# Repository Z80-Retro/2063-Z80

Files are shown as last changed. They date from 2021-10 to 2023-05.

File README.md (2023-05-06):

# Retro Z80 CPU Board

This project was designed to run CP/M 2.2 from an SD card.  It should be an attainable goal for anyone that can solder through-hole parts to assemble it. Note that J10 is an optional header that allows a Sparkfun SD card breakout board [DEV-13743](https://www.digikey.com/en/products/detail/sparkfun-electronics/DEV-13743/5881845) to used instead of soldering on the surface-mount SD socket part.

Here is an easy-to-find direct link to the [PDF of the schematic](https://github.com/Z80-Retro/2063-Z80/raw/main/2063-Z80.pdf) for a quick view.

## Where to get Boards & Software

* You can order boards from any prototype PCB vendor.  For example, I show how you can order these boards from [JLCPCB](https://jlcpcb.com/) or [OSHPark](https://oshpark.com/) by uploading the gerber files found in the releases of this and the flash programmer projects as shown in this [Z80 Retro! - How To Order PC Boards](https://youtu.be/AUg_sbPnzn0) video on YouTube.
  - Gerber files for the CPU board: [2063-Z80-v3](https://github.com/johnwinans/2063-Z80/releases/download/v3/2063-Z80-gerbers.zip)
  - Gerber files for the FLASH programmer: [2065-Z80-programmer-v2](https://github.com/johnwinans/2065-Z80-programmer/releases/download/v2.0/2065-Z80-programmer-gerbers.zip) (This is used with a Raspberry PI to program the FLASH chip on the CPU board.)

* Software for this project can be found in my [2063-Z80-cpm](https://github.com/johnwinans/2063-Z80-cpm) repo.

* Note that the [FLASH programmer](https://github.com/johnwinans/2065-Z80-programmer) has been designed to work with a Raspberry PI in the event that you don't already own such programmer.  This companion programmer PCB should cost about $2 more when it is ordered at the same time as the CPU board from JLCPCB or other similar proto-board shops as shown in the [Z80 Retro! - How To Order PC Boards](https://youtu.be/AUg_sbPnzn0) video on YouTube.

## Links to Related Material

* A youtube playlist discussing this project and how to build your own can be found in [John's Basement](https://www.youtube.com/watch?v=oekucjDcNbA&list=PL3by7evD3F51Cf9QnsAEdgSQ4cz7HQZX5)
* A PDF version of the schematic can be found [here](2063-Z80.pdf).
* Here is the as-built [BOM](2063-Z80.md) with links to the datasheets for all the parts.
* Here is another [BOM](2063-Z80-sockets.md) with links to sockets for the chips.
* To configure a new PI for use with this programmer board as well as to develop Z80 code 
for the Z80 Retro board, see this [PI Setup Guide](https://github.com/johnwinans/raspberry-pi-install)
* More software for this project will be added as it evolves.

## Links to Related Datasheets Seen On YouTube

* [Z80 Datasheet PS0178](https://www.zilog.com/docs/z80/ps0178.pdf) with detailed timing diagrams.
* [Z80 User Manual UM0080](http://www.zilog.com/docs/z80/um0080.pdf) with detailed descriptions of each instruction.
* [Z80 Assembly Language Programming Manual](http://zxevo.ru/inc/Zilog_Z80_assembly_language_programming_classic.pdf) - The original version of the instructions without the OCR errors present in UM0080.
* [Z80 CPU Peripherals User Manual UM0081](http://www.zilog.com/docs/z80/um0081.pdf) discusses the CTC and SIO.
* [Z80 Family Product Specifications Handbook - 1984](http://www.bitsavers.org/components/zilog/z80/Z80_Family_Product_Specifications_Handbook_Feb84.pdf) has nicer pictures of the SIO registers.
* [Wikipedia UART Article](https://en.wikipedia.org/wiki/Universal_asynchronous_receiver-transmitter)
* [AY-3-1015D UART Datasheet](https://rocelec.widen.net/view/pdf/bvesdj0cqf/GSIIS01845-1.pdf) (Has a discussion of the 16X bit-rate clock with diagrams etc. applicable to all UARTs.)

## Serial Port Cable Parts

* [How to make IDC cables](https://youtu.be/gZ420Z-8HuU) for the serial ports.
* [IDC 2x5 connectors](https://www.amazon.com/gp/product/B07S1NFG4S)
* [IDC D-SUB 9-pin connectors (Digikey)](https://www.digikey.com/en/products/detail/assmann-wsw-components/A-DSF-09LPIII-Z/924263)
* [IDC D-SUB 9-pin connectors (Amazon)](https://www.amazon.com/Uxcell-a15030600ux0494-Female-Connector-Ribbon/dp/B00YM41NTW)

## Parallel Port Cable Parts

* [IDC 2x13 connectors](https://www.amazon.com/gp/product/B07RXK96GV)
* [IDC D-SUB 25-pin connectors (Digikey)](https://www.digikey.com/en/products/detail/amphenol-icc-commercial-products/L17DBFRA25S/1972210)
* [IDC D-SUB 25-pin connectors (Amazon)](https://www.amazon.com/Fielect-Female-Adapter-Connector-Ribbon/dp/B082GMDNTS)

## Ribbon Cable

* [40-conductor (Amazon)](https://www.amazon.com/Eowpower-40Pin-40Way-Rainbow-Ribbon/dp/B079KQ6K3Y) - peel off a
 26-pin strip and a 10-pin strip to make one parallel and one serial cable (cut the 10-pin strip in half length-wise to make two serial cables.

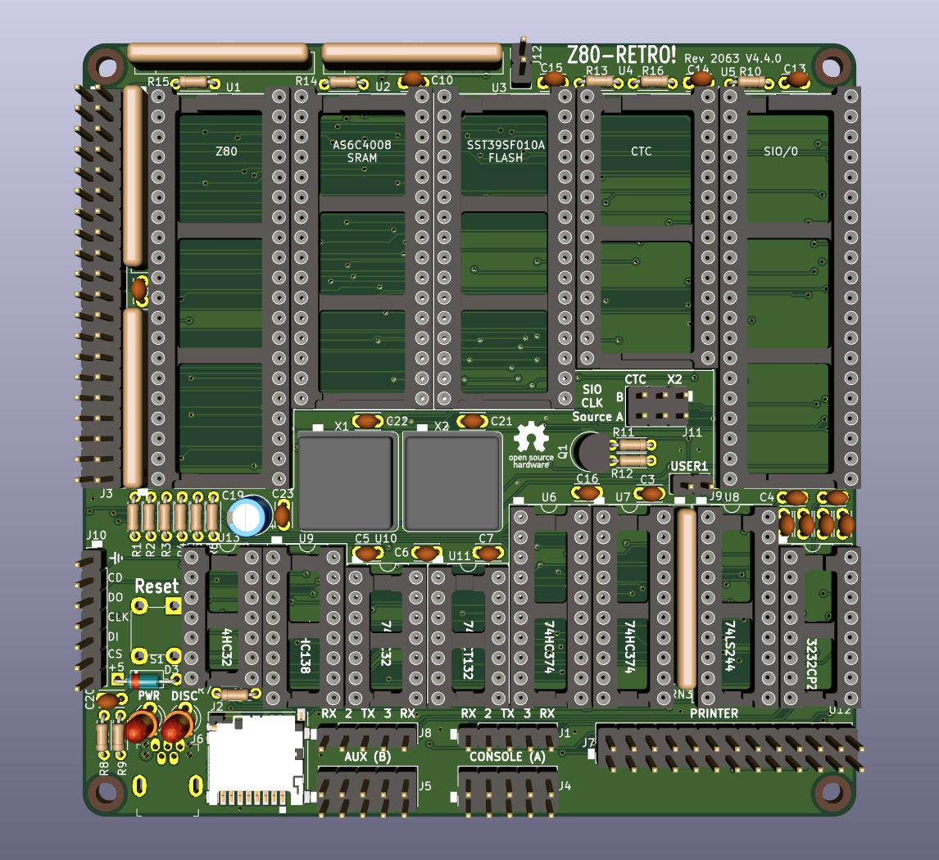
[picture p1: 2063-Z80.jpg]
PC Board Image Retro Z80 CPU Board Rev 2


# Release Notes

## V4.4.0

- Change footprint for SD socket to increase the pad size for mounting the case.
- Label R15 and R16 as DNP.
- Move the [diffs](./diffs/) into their own directory.
- V4.3.3 to V4.4.0 schematic [visual diff](https://github.com/Z80-Retro/2063-Z80/raw/main/diffs/2063-Z80-V4.3.3-V4.4.0-delta-schematic.pdf)
- V4.3.3 to V4.4.0 PCB [visual diff](https://raw.githubusercontent.com/Z80-Retro/2063-Z80/main/diffs/2063-Z80-V4.3.3-V4.4.0-delta-pcb.png)

## V4.3.3

- Increase the values of the RS232 charge pump (on U12) capacitors to improve filtering.
- V4.3.2 V4.3.3 schematic [visual diff](https://github.com/Z80-Retro/2063-Z80/raw/main/diffs/2063-Z80-V4.3.2-V4.3.3-delta-schematic.pdf)
- V4.3.2 V4.3.3 PCB [visual diff](https://github.com/Z80-Retro/2063-Z80/raw/main/diffs/2063-Z80-V4.3.2-V4.3.3-delta-pcb.png) (no changes)

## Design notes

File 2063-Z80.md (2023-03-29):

# 2063-Z80.sch

## Tue Mar 28 20:43:38 2023

## Eeschema 5.1.5+dfsg1-2build2

## Component Count:86

Ref | Qty | Value | Digikey | Datasheet | Description
----|-----|-------|---------|-----------|------------
C1, C11, C12, C20 | 4 | .47 | 399-14039-1-ND | https://api.kemet.com/component-edge/download/datasheet/C315C474K5R5TA7303.pdf | Unpolarized capacitor, small symbol
C2, C3, C4, C5, C6, C7, C8, C9, C10, C13, C14, C15, C16, C21, C22, C23 | 16 | .1 | 399-9859-1-ND | https://api.kemet.com/component-edge/download/specsheet/C315C104M5U5TA7303.pdf | Unpolarized capacitor, small symbol
C17 | 1 | .1 | 1276-1935-1-ND | https://www.mouser.com/datasheet/2/585/MLCC-1837944.pdf | Unpolarized capacitor, small symbol
C18 | 1 | 10uF | 1276-1298-1-ND | https://media.digikey.com/pdf/Data%20Sheets/Samsung%20PDFs/CL21A106MQFNNNE_Spec.pdf | Polarized capacitor, small US symbol
C19 | 1 | 10uF | P975-ND | https://industrial.panasonic.com/cdbs/www-data/pdf/RDF0000/ABA0000C1059.pdf | Polarized capacitor, small US symbol
C24 | 1 | .1 | 1276-1935-1-ND | https://www.mouser.com/datasheet/2/585/MLCC-1837944.pdf | Unpolarized capacitor, small symbol
D1, D2 | 2 | LED_ALT | 1080-1122-ND | https://media.digikey.com/PDF/Data%20Sheets/Everlight%20PDFs/ds300034.pdf | Light emitting diode, filled shape
D3 | 1 | 1N914 | 1N4148FSCT-ND | http://www.vishay.com/docs/85622/1n914.pdf | 100V 0.3A Small Signal Fast Switching Diode, DO-35
H1, H2, H3, H4 | 4 | MountingHole |  |  | Mounting Hole without connection
J1, J8 | 2 | Conn_01x05 | S1011EC-05-ND | https://media.digikey.com/PDF/Data%20Sheets/Sullins%20PDFs/xRxCzzzSxxN-RC_ST_11635-B.pdf | Generic connector, single row, 01x05, script generated (kicad-library-utils/schlib/autogen/connector/)
J2 | 1 | DM3D-SF(41) | H126097CT-ND (alternate: 114-00841-68-1-ND) | https://www.hirose.com/product/document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 | Micro SD Card Socket with card detection pins
J3 | 1 | Conn_02x20 | S2011EC-20-ND | https://drawings-pdf.s3.amazonaws.com/11636.pdf | Generic connector, double row, 02x20, counter clockwise pin numbering scheme (similar to DIP packge numbering), script generated (kicad-library-utils/schlib/autogen/connector/)
J4, J5 | 2 | Conn_02x05 | 1849-1002-ND |  | Generic connector, double row, 02x05, odd/even pin numbering scheme (row 1 odd numbers, row 2 even numbers), script generated (kicad-library-utils/schlib/autogen/connector/)
J6 | 1 | 0548190519 | A135698-ND | https://www.molex.com/pdm_docs/sd/548190519_sd.pdf | CONN RCPT USB2.0 MINI B 5P R/A
J7 | 1 | Conn_02x13 | S2011EC-13-ND | https://drawings-pdf.s3.amazonaws.com/11636.pdf | Generic connector, double row, 02x13, top/bottom pin numbering scheme (row 1: 1...pins_per_row, row2: pins_per_row+1 ... num_pins), script generated (kicad-library-utils/schlib/autogen/connector/)
J9, J12 | 2 | Conn_01x02 | S1011EC-02-ND | https://media.digikey.com/PDF/Data%20Sheets/Sullins%20PDFs/xRxCzzzSxxN-RC_ST_11635-B.pdf | Generic connector, single row, 01x02, script generated (kicad-library-utils/schlib/autogen/connector/)
J10 | 1 | Conn_01x07 | S1011EC-07-ND | https://media.digikey.com/PDF/Data%20Sheets/Sullins%20PDFs/xRxCzzzSxxN-RC_ST_11635-B.pdf | Generic connector, single row, 01x07, script generated (kicad-library-utils/schlib/autogen/connector/)
J11 | 1 | Conn_02x03 | 2057-PH2-06-UA-ND | https://app.adam-tech.com/products/download/data_sheet/202065/ph2-xx-ua-data-sheet.pdf | Generic connector, double row, 02x03, odd/even pin numbering scheme (row 1 odd numbers, row 2 even numbers), script generated (kicad-library-utils/schlib/autogen/connector/)
LOGO1 | 1 | OSHW_Logo |  |  | Open Hardware logo, small
LOGO2 | 1 | OSHW_Logo |  |  | Open Hardware logo, small
NT1, NT2 | 2 | Net-Tie_2 |  | ~ | Net tie, 2 pins
Q1 | 1 | PN2222 | 1514-PN2222APBFREE-ND | https://my.centralsemi.com/datasheets/PN2221-2222A.PDF | NPN transistor, emitter/base/collector
R1, R3, R5 | 3 | 2K7 | CF18JT2K70CT-ND | https://www.seielect.com/catalog/sei-cf_cfm.pdf | Resistor
R2, R4, R6 | 3 | 4K7 | CF18JT4K70CT-ND | https://www.seielect.com/catalog/sei-cf_cfm.pdf | Resistor
R7, R10, R13, R14 | 4 | 10K | CF18JT10K0CT-ND | https://www.seielect.com/catalog/sei-cf_cfm.pdf | Resistor
R8, R9 | 2 | 680 | CF18JT680RCT-ND‎ | https://www.seielect.com/catalog/sei-cf_cfm.pdf | Resistor
R11, R12 | 2 | 1K | CF18JT1K00CT-ND‎ | https://www.seielect.com/catalog/sei-cf_cfm.pdf | Resistor
R15, R16 | 2 | 120 | CF18JT120RCT-ND | https://www.seielect.com/catalog/sei-cf_cfm.pdf | Resistor
RN1, RN2, RN3, RN4, RN5 | 5 | 10K | 4609X-101-103LF-ND‎ | https://www.bourns.com/docs/Product-Datasheets/4600x.pdf | 8 resistor network, star topology, bussed resistors, small symbol
S1 | 1 | 1825910-6 | 450-1650-ND | https://www.te.com/commerce/DocumentDelivery/DDEController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 | SWITCH TACTILE SPST-NO 0.05A 24V
U1 | 1 | Z80-CPU | 269-3898-ND | https://www.zilog.com/manage_directlink.php?filepath=docs/z80/um0080 | 8-bit General Purpose Microprocessor, DIP-40
U2 | 1 | AS6C4008-55PCN | 1450-1178-5-ND‎ | https://www.alliancememory.com/wp-content/uploads/pdf/AS6C4008.pdf | 512K x 8 Low Power CMOS RAM, DIP-32
U3 | 1 | SST39SF010 | SST39SF010A-70-4C-PHE-ND‎ | https://ww1.microchip.com/downloads/en/DeviceDoc/20005022C.pdf | Silicon Storage Technology (SSF) 128k x 8 Flash ROM
U4 | 1 | Z80-CTC | 269-3914-ND | http://www.zilog.com/docs/z80/ps0181.pdf | Z80 CTC DIP-28
U5 | 1 | Z80-SIO-0 | 269-5062-ND‎ | http://www.zilog.com/docs/z80/ps0183.pdf | SCC Serial Communication Controller, DIP-40
U6, U7 | 2 | 74HC374 | 296-12806-5-ND | https://www.ti.com/lit/ds/symlink/cd74hct374.pdf | 8-bit Register, 3-state outputs
U8 | 1 | 74LS244 | 296-36148-5-ND | https://www.ti.com/lit/ds/symlink/sn74ls241.pdf | 8-bit Bus Buffer 3-State outputs
U9 | 1 | 74HC138 | 296-SN74HC138AN-ND | https://www.ti.com/lit/ds/symlink/sn54hc138.pdf | Decoder 3 to 8 active low outputs
U10, U13 | 2 | 74HC32 | 296-12803-5-ND | https://www.ti.com/lit/ds/symlink/cd74hc32.pdf | Quad 2-input OR
U11 | 1 | 74HCT132 | 296-2090-5-ND | https://www.ti.com/lit/ds/symlink/cd74hc132.pdf | Quad 2-input NAND Schmitt trigger
U12 | 1 | ICL3232CPZ | ICL3232CPZ-ND‎ | https://www.renesas.com/us/en/document/dst/icl3221-icl3222-icl3223-icl3232-icl3241-icl3243-datasheet | 3.0V to 5.5V, Low-Power, up to 1Mbps, True RS-232 Transceivers Using Four 0.1μF External Capacitors
U20 | 1 | LM1117-3.3 | NCP1117ST33T3GOSCT-ND | https://www.onsemi.com/pdf/datasheet/ncp1117-d.pdf | 800mA Low-Dropout Linear Regulator, 1.8V fixed output, TO-220/TO-252/TO-263/SOT-223
X1 | 1 | ACH-10.000MHZ-EK | 535-9167-5-ND | https://abracon.com/Oscillators/ACH.pdf | Crystal Clock Oscillator, DIP8-style metal package
X2 | 1 | ECS-2100A-018 | XC231-ND‎ | https://ecsxtal.com/store/pdf/ecs_2100.pdf | Crystal Clock Oscillator, DIP8-style metal package

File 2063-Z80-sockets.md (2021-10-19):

## IC Sockets

You can buy fancy expensive ones, or you can buy cheap ones.
I used the cheap ones.  

Alternately, you can just solder the chips into the PCB.

As a tinkerer, the thing that is wrong with that is that it makes it very hard to 
recycle/repurpose the chips for something else in the future.  And with the 2021
chip-shortage in full-force on as I type this, being able to recycle chips is 
VERY appealing!

Be honest with yourself before sinking more money into sockets than the cost of the chips 
that go into them.  I expect the cheap ones to last for at least a decade or two.  Cheap
sockets in my hobby projects from 30 years ago are still doing fine.

Gold plating is better than tin.  Machined pins (see the oscillator sockets) are better than
stamped spring-metal pins. 

Ref | Qty | Value | Digikey | Datasheet | Description
----|-----|-------|---------|-----------|------------
U1,U5 | 2 | Socket | AE10008-ND | http://www.assmann-wsw.com/uploads/datasheets/ASS_0810_CO.pdf | DIP-40
U2,U3 | 2 | Socket | 2057-ICS-632-T-ND | https://app.adam-tech.com/products/download/data_sheet/199581/ics-6xx-t-data-sheet.pdf | DIP-32
U4 | 1 | Socket | 2057-ICS-628-T-ND | https://app.adam-tech.com/products/download/data_sheet/199581/ics-6xx-t-data-sheet.pdf | DIP-28
U10,U13,U11 | 3 | Socket | 2057-ICS-314-T-ND | https://app.adam-tech.com/products/download/data_sheet/199582/ics-3xx-t-data-sheet.pdf | DIP-14
U9,U12 | 2 | Socket | 2057-ICS-316-T-ND | https://app.adam-tech.com/products/download/data_sheet/199582/ics-3xx-t-data-sheet.pdf | DIP-16
U6,U7,U8 | 3 | Socket | 2057-ICS-320-T-ND | https://app.adam-tech.com/products/download/data_sheet/199582/ics-3xx-t-data-sheet.pdf | DIP-20

# Sockets for the Oscillators

Metal can oscillators have wires for pins.  In my experience they tend to sit loosely in 
regular sockets and do better in machined-pin sockets.

For these 4-pin parts you have two options.  Either order a relatively expensive pair of 
sockets ready to solder in as-is or order a pair with extra pins and remove the ones you don't
want and then solder in. 

I went the latter route because I already had several 8-pin sockets on hand.

To remove the extra pins from the fully loaded sockets, use a small pliers to grab the pins 
to be removed from the bottom of the socket and push them out the top.

Look at the photos of each type and you'll see what I mean.

Ref | Qty | Value | Digikey | Datasheet | Description
----|-----|-------|---------|-----------|------------
X1,X2 | 2 | Socket | ED90427-ND | https://www.mill-max.com/catalog/download/2017-11:134.pdf | OSC-4 (a whopping $1.50 each!)
X1,X2 | 2 | Socket | AE10011-ND | http://www.assmann-wsw.com/uploads/datasheets/ASS_4852_CO.pdf | DIP-8 ($.50 each)

## Shorting Blocks

These are for selecting the clock sources for the SIO, user jumper, and 
RS-232 TX/RX pin number selection.

Ref | Qty | Value | Digikey | Datasheet | Description
----|-----|-------|---------|-----------|------------
J11,J9,J1,J8 | 7 | S9337-ND | https://s3.amazonaws.com/catalogspreads-pdf/PAGE128-129%20.100%20JUMPER.pdf | Shorting Block | Shorting Jumper

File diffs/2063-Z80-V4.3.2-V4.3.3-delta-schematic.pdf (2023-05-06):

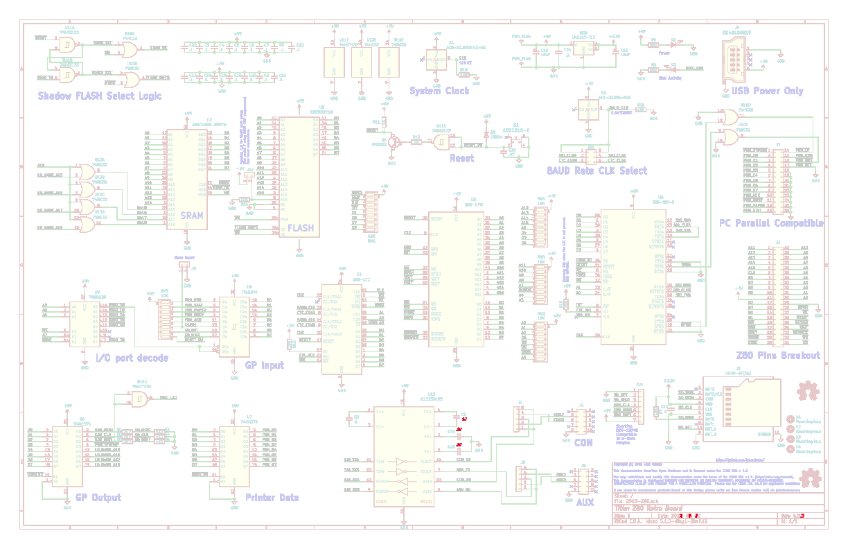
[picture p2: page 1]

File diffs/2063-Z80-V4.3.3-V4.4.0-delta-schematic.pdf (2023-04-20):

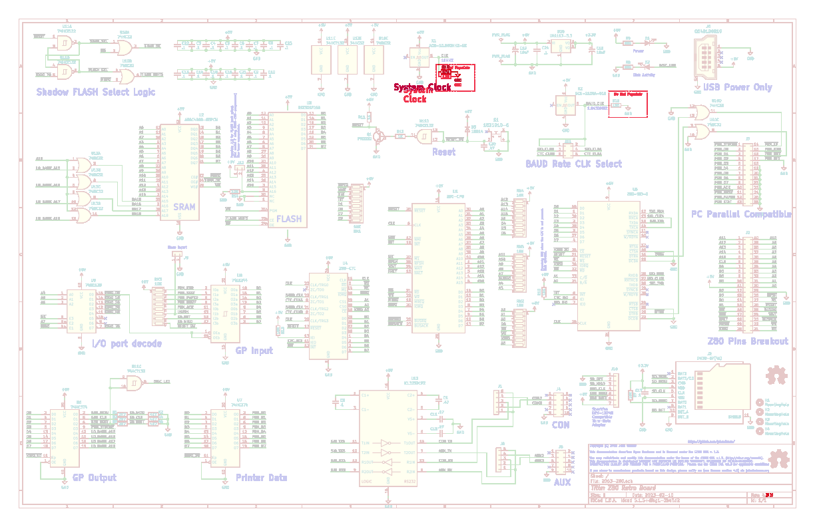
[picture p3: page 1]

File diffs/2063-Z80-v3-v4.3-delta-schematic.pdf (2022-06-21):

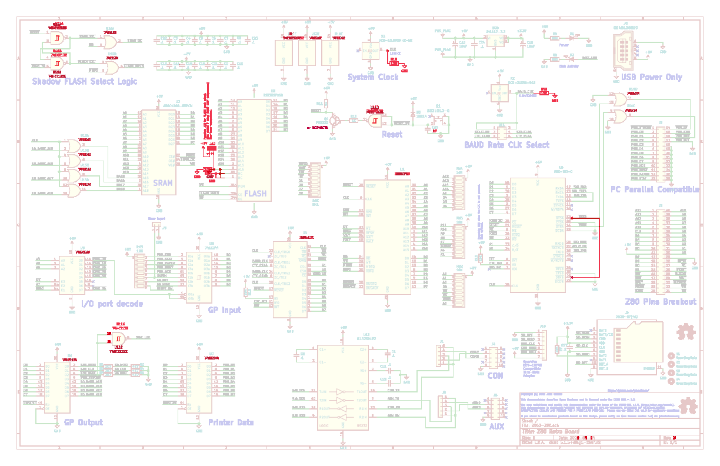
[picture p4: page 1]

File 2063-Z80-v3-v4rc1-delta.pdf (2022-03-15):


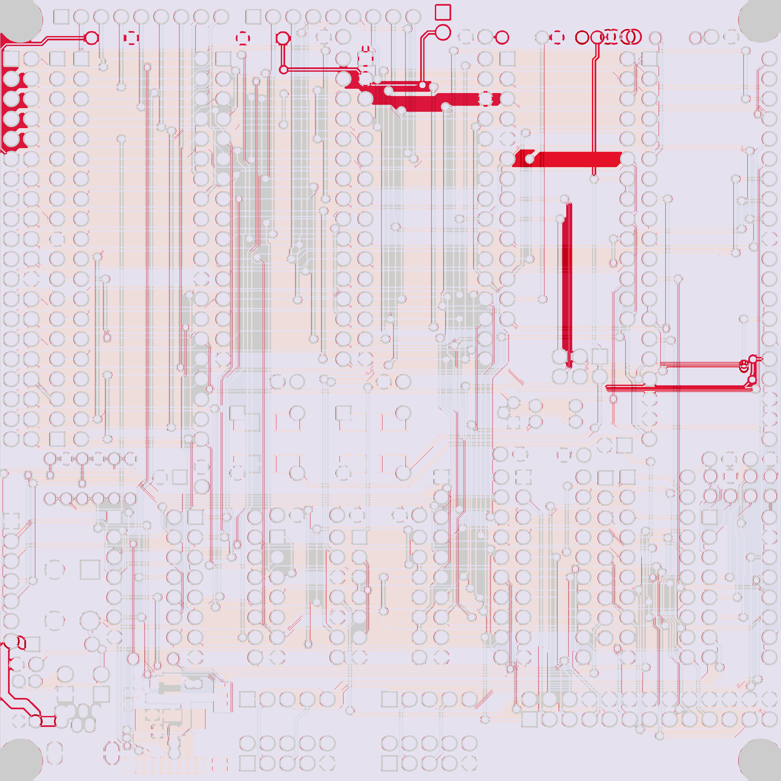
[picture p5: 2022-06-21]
diffs/2063-Z80-v3-v4.3-delta-pcb.png

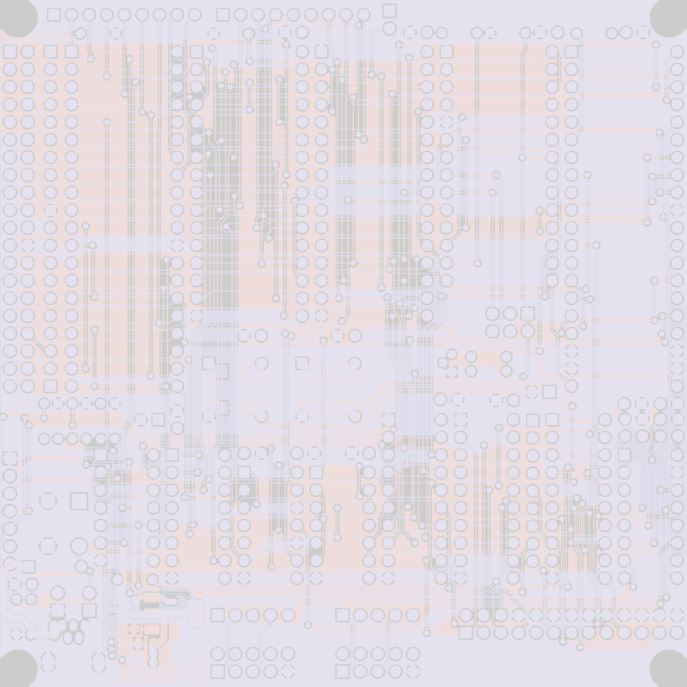
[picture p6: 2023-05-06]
diffs/2063-Z80-V4.3.2-V4.3.3-delta-pcb.png

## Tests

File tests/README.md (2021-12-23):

# Basic test applications for the Z80 Retro board.

These applications require the use of `z80asm`.  You can install it like this:

	sudo apt install z80asm

Assemble these test applications like this:

	make world

Download them into the FLASH by using the `flash` programming application in the 
[2065-Z80-programmer](https://github.com/johnwinans/2065-Z80-programmer/tree/master/pi) 
project in github.  If you cloned the 2065-Z80-programmer project into your
home directory and built it on your PI then you can program these files like this:

	~/2065-Z80-programmer/pi/flash < blinky1.bin

## Test Programs

### blinky1.asm
Flash the SD card select LED.  This runs entirely from the FLASH (does not use SRAM).

### blinky2.asm
Flash the SD card select LED.  This copies itself from the FLASH into the SRAM and then runs from there.

### blinky3.asm
Flash the SD card select LED and at the same time, count on the printer port data lines.

### hello_sio1.asm
Test the SIO ports in polled mode.

### hello_sio2.asm
Test the SIO ports in IRQ mode.

### hello_ctc2.asm
Test the CTC with IRQs and print an 'uptime' counter using the SIO.

## bank_select.asm
Test the SRAM blank select logic by padding and dumping regions of memory in different banks.

## hello_lpt.asm
Test the printer port by priting a 'hello world' type message.

## hello_lpt2.asm
Test the printer port by priting gaudy banners.

## io.asm
Equates for the IO ports on the Z80 Retro! board.

## sio.asm
Simple driver for the SIO.

## hexdump.asm
A library to print a memory hex dump.

## ctc.asm
Simple driver for the CTC.

## lpt.asm
Simple driver for the printer.

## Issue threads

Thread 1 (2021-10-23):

Rev 3: /PRN_LF should not be originated from /RTSA

johnwinans, 2021-10-23:
The /PRN_LF signal is intended to be manually changed under software control only.
I ran out of space on the PCB and decided to use an output pin on the SIO as a general-purpose port.  It will work if the intent is to drive the pin low.  But it will not work as expected when driving it high.

Z80 Family CPU Peripherals User Manual UM008101-0601 says this on page 212:

> RTSA, RTSB Request To Send (outputs, active Low). When the /RTS bit is set, the RTS output goes Low. When the RTS bit is reset in the Asynchronous mode, the output goes High after the transmitter is empty.

Therefore, driving the pin low will work as expected.

To drive it high an a Rev 3 board, there are two options:

1. Cut the track on J7 pin 14 and wire it to +5v (which is a better hard-wired default than low)
2. Cut the track on U10 pin 13 and add a wire to connect it to U5, pin 25 /DTRB (which is a GP output pin)

In Rev 4, I will re-route this pin to U5, pin 25 (option 2 above)

johnwinans, 2021-12-01:
Done in Rev 4

Closed 2021-12-01.

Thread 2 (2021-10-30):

Low slew-rate power might not assert /RESET long enough

johnwinans, 2021-10-30:
After doing some testing with a range of USB power supplies/chargers I have noticed that one of mine will ramp up the voltage slow enough to prevent the /RESET signal from remaining asserted long enough to properly start the Z80.

This has no impact on the ability to use the reset button.

To 'fix' this, I changed C20 to .47uF.  This will keep the /RESET signal asserted five times longer after initial power-up and "works for me" on all the USB power supplies that I have around to test with.

Increasing the size of C20 is OK within reason.  Keep in mind that the reset-button (S1) shorts out C20 to reset the system.  The switch will not last very long if C20 is large!  I'd advise not using anything more than 1uF for C20.

johnwinans, 2021-12-01:
I changed C20 to .47uF in the Rev4 version of the schematic.

Closed 2021-12-01.

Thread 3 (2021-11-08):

Allow alternate SD card sockets

johnwinans, 2021-11-08:
Due to the galactic parts-shortage, Digikey, Mouser, and Newark are all on backorder for the Hirose DM3D-SF SD card socket in the Rev 3 design.

If a Rev4 board is produced, adjust the footprint to allow for an alternate socket (such as the Molex 1051620001) to be used.
[It looks like the Molex could be made to fit on the same pads IFF the keep-out areas are increased and a second card-det landing is added.]

sebsch2000, 2021-11-17:
Amphenol 114-00841-68 has the same footprint as the Hirose part. Right now Mouser has 4.813 of them in stock (Mouser part no. 523-114-00841-68).

jackrubin, 2021-11-18:
Who’s on first? Does this mean that there is no need for a Rev 4 board spin and I can build out one of your Rev 3 sets?

Thanks,
Jack

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

sebsch2000, 2021-11-18:
Well, I built a rev 3 board this week. I ordered the parts from Mouser and Digikey. Had to replace the Hirose connector with the Amphenol one and the ICL3232CPZ (U12) with the MAX232N which is basically the same. The test programs worked as they should.

jackrubin, 2021-11-18:
That’s good – if you still have a spare, I’d like to buy one board + programmer set from you. Please let me know the cost and PayPal info.

Thanks,
Jack

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

johnwinans, 2021-11-18:
How did I not find the Amphenol 114-00841-68 part????  That is fantastic!
I'll add a note marking that as an alternate and take a pass on the footprint hacking.

jackrubin, 2021-11-26:
Please push the rev/bom changes up to the github repository when you get a chance.
Thanks!

johnwinans, 2021-12-01:
There is at least one alternate that does not require a footprint modification.  I am not going to leave well enough alone.

Closed 2021-12-01.

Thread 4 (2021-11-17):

Add A16 jumper to FLASH

johnwinans, 2021-11-17:
Add a jumper & pullup on the FLASH A16 pin to allow alternate BOOT images.
Note that this is only useful when using a stand-alone FLASH programmer as the in-circuit programmer design will not work when A16(, A17 or A18) is high.

johnwinans, 2021-12-01:
So done in Rev4

Closed 2021-12-01.

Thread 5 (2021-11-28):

Clock overshoot

johnwinans, 2021-11-28:
Add terminating resistors to the clock signal traces to reduce overshoot & ringing.

johnwinans, 2021-12-01:
I added end-terminating resistors to Rev4.  It looks like 120 will reduce the concern a bit.
Source-termination might help too but I am out of space on the board.

Closed 2021-12-01.

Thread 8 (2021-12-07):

10MHZ clock might be too fast for the FLASH chip I specified.

johnwinans, 2021-12-07:
While my board has been running fine at 10MHZ, the timing on FLASH_MREQ is too tight to meet the official worst-case specification... even with the 55ns version of the FLASH.

The solution if you run into trouble is to run the main clock at 8MHZ.  I will change the design to officially run at 8.

On the YouTube comments: https://www.youtube.com/watch?v=w5LYCHml4A8

Torshak observed:
As always, great and very helpfull video.
I have a observation regarding memory access time though. I am trying to read Z80 opcode fetch timings, and I don't think you have entire 150ns. Yes, you have 1.5 periods, but... MREQ signal does not fall together with clock falling egde but it takes it up to 55 ns. Then Z80 expects data to be stable 25 ns before rising edge of the clock. (all timings for 10Mhz version) so you are left with 70ns, and that's wihtout glue logic. Of course this is almost the absolute worst scenario. Unless I am reading it wrong... which would not be the first time ;)

Then I replied with this:
BLAST IT ALL!!!!  I was looking at a page of the datasheet that included a wait-state in the diagram!   It looks like the 55 and 25 numbers are right for the 10MHZ Z80.. The FLASH that I used has a 70ns access time (and the RAM is 55).  Revising my understanding and NOT including a stinking wait-state the tightest memory cycle duration is 150ns - 55ns - 25ns = 70ns.
Fortunately, the SRAM has no decoding per-se  and the OE to DATA time is 30ns (which is fine with the extra U10 27ns delay.)
The FLASH is a bit more of a problem.  FLASH_MREQ can be delayed by U10 by up to 27ns.
I hang my head in shame!
Luckily, at 8MHZ, we see 125*1.5 - 60 - 30 = 97.5nsec
The worst-case FLASH_MREQ time (delayed by 27ns) is then 70.5nsec  :-D
I think I will /officially/ slow the main clk to 8MHZ and observe that I have been living on the edge by overclocking mine at 10!

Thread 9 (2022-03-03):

Is board silkscreen for U11 incorrect on 2063.4?

joelburton, 2022-03-03:
The board silkscreen on U11 is `'00` (suggesting a 74HCT00) --- however, the schematic/values/BOM suggests that is a 74HCT132.

Is this just a mislabel on the board? Or am I misunderstanding something significant?

johnwinans, 2022-03-03:
The 132 is the correct part!  The reason is that U11D must have a
Schmitt trigger.

Thanks for mentioning it. I will update the silkscreen.

I recorded a video explaining the need for the Schmitt here:

https://youtu.be/LDce9foQ2Ag

I have been working on a playlist discussing every detail of this
project here:

https://www.youtube.com/playlist?list=PL3by7evD3F51Cf9QnsAEdgSQ4cz7HQZX5

This month I will be adding details on how to port CP/M onto it.

-John

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

johnwinans, 2022-03-22:
I updated the silkscreen.  It will appear in v4rc2

Closed 2022-03-22.

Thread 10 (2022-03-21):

Possibly useful advice: connecting console to computer w/o RS232 serial

joelburton, 2022-03-21:
I have a RS232 terminal, but a friend building the board does not and doesn't even have a serial port on her computer. The design doesn't expose an easy way to connect a 5v Tx/Rx for a FTDI->USB connection.

I doubt there's space to add that to the board (maybe above the printer connection?), but something that is working for us is a RS232 voltage -> 5v converter (we're using https://www.amazon.com/gp/product/B07LBDZ9WG/). This can be connected to a standard FTDI USB cable.

johnwinans, 2022-03-21:
This is a good idea... and it figures... I *just* ordered some v4 boards last week to verify that design. :-D

I don't have a serial port on mine either.  I use a USB/RS232 adapter like one of these:
https://www.amazon.com/Sabrent-RS-232-Adapter-Prolific-SBT-USC6K/dp/B000A1KD1K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

But this makes me think.  There are likely a number of potential users the might want to go USB-direct.

With the product you mention, you could solder in wires to the U12 pin holes and run them to the adapter board. With the header on the side next to the DB25 seems awkward to try to directly mate.  (That is actually how I did the first version of this board as I messed up U12 completely.)

If you leave U12 unpopulated, we could add a 1-row header that could match an available 3rd party USB TTL adapter.  These appear to be pinned the same way.
https://www.sparkfun.com/products/14050
https://www.sparkfun.com/products/9716

I'm not sure that I'd want to power the Retro board from a PC USB port... and would definitely not think of powering a PI (FLASH programmer) from it.  (I *always* Power my retro FROM the PI when I have the FLASH programmer installed.)  But it might be worth providing a way to add a jumper or something to allow it.

It should be easy to put a header just south of the printer port or even under U12 (so you could either install a header OR the U12 socket.)
If you install a right-angle header then the adapter would lay flat (which would be my preference.)

What do you think?

joelburton, 2022-03-21:
Putting the headers in the center of U12 is an interesting idea an could help those that don't populate it; that wouldn't use up any of the precious board space :)

joelburton, 2022-03-21:
Those Sparkfun boards are what a lot of other projects (like the rc2014s) make their pins compatible for, so a lot of people have them lying about.

johnwinans, 2022-03-22:
I was torn between the header at the bottom under the printer port and overlaying U12.
I like the idea of building the board with both the U12 socket and J13 installed so that one can flip back & forth between using TTL and RS232.

What do you think of this PCB arrangement?

https://github.com/johnwinans/2063-Z80/blob/add-ttl-serial-header/2063-Z80.jpg

joelburton, 2022-03-22:
Looks awesome to me!

johnwinans, 2022-03-22:
Coolness!  I will make it happen and merge it in tonight!

Closed 2022-03-23.

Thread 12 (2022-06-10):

Question on part selection for SMD capacitors

dburr, 2022-06-10:
Any reason in particular you chose 0603 parts for C17 and C24, yet went with an 0805 for C18? I, uh, may have accidentally lost the 0603 parts I ordered (tiny little buggers....and slippery too) and rather than wait for another Digikey order, I decided to try and shoehorn an 0805 part (which I had on hand) in place, and it fits!

Also, C18 is listed on the BOM as a polarized capacitor, and to my knowledge, SMD ceramic caps are unpolarized. Mistake, or is there some weird polarized SMD ceramic capacitor that I am unaware of?

johnwinans, 2022-06-11:
I /should/ have used 0805 parts for all the surface mount to make it easier.  You can easily put an 0603 on an 0805 footprint, so it would have been easier to change the parts too.

I will leave this issue open until next time I tinker with this board and make this change.

Thanks for noticing!

Closed 2023-02-11.

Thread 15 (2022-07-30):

Bad RAM part number?

zxMarce, 2022-07-30:
John, the silks on `2063.4.3` say `AS6C1008` (1MB) instead of `AS6C4008` (4MB) as the part number for the RAM chip. This can be (is?) kinda confusing.
The typo is also present in the 3D model picture in the main project page; noticed this while browsing parts to place an order.

On the other hand, the part itself is an AS6C4008 when checking the part's properties in KiCAD's PCB and schematic editors. Looks like just the silks are the only ones affected.

Marcelo.

johnwinans, 2022-07-30:
You are absolutely right.  I'm on it.  :-(

johnwinans, 2022-07-30:
Thanks.  Looks like it is time for a v4.3.1

zxMarce, 2022-07-30:
Anytime. Glad it helped.

Closed 2022-07-30.

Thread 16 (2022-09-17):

Invalid FLASH signature: 0x2020 != 0xbfb5

Steve-Sexton, 2022-09-17:
I've flashed several files to the retro board with no problems.

Last time I tried to flash something to the board I get:
"Product ID: 0x20, 0x20"
"Invalid FLASH signature: 0x2020 != 0xbfb5"

What is the best method to determine if the problem is with the Raspberry PI, Programming Board or the Retro Board?

johnwinans, 2022-09-17:
What happens if it is not plugged into the z80 board?

What rev of the programmer board do you have? Does it have pullups on the 23017 reset inputs?

Steve-Sexton, 2022-09-17:
I'm using  Programmer Rev 2065.2 and  Z80-Retro Rev 2063.4.2

Working now, something must have been in an unknown state.

Unplugged the ribbon cable from the Programmer.
Attempted to flash blinky1
RPI reported many flach.c mcp23017_write errors
Unplugged the Programmer J3 - PI power jumper
Plugged the ribbon cable back into the RPI
Plugged the jumper across Programmer J3 - PI power
Flashed blinky with no errors.... LED in blinking

Thanks

On Sat, Sep 17, 2022 at 4:10 PM John Winans ***@***.***>
wrote:

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

johnwinans, 2022-12-08:
I'm glad to know this case is closed!

Closed 2022-12-08.

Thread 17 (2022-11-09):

Is this a Raspberry pi extension project. or z80 cp/m

Amstrad-nutter, 2022-11-09:
A Raspberry PI project?
As you cannot seem to Communicate with z80 Repo, without one.
Compile the Files, without one
Program the flash, without one
Create as SD card image, without one
Please for us that use the Precious Pi’s we have running Infrastructure e.g., Home Assistant an MQTT Server etc.
Can you just run MAKE and zip the resulting files. and end the frustration.
So many of us who have Device programmers and dormant z80 retro’s running nop loop tests can join in the fun too.
Please Help us.
Many thanks.

johnwinans, 2022-12-08:
I am not sure what you are proposing.
You can run the build and SD-card programming on any Linux box.
You can also program the FLASH with any suitable programmer.
No PI is needed.

johnwinans, 2023-02-11:
I just re-read this.... apparently I completely missed the request for binaries in there.
OK, I'll build a release with binaries for this project and the related CP/M part of the project.

johnwinans, 2023-02-11:
See version V4.3.3 with fresh PDF and binaries in the attached zip file

Closed 2023-02-11.

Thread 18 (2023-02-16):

Minor Comment Issue in file tests/hello_ctc2a.asm

dennowiggle, 2023-02-16:
tests/hello_ctc2a.asm contains a comment that references the wrong section in the manual.

Line 79 Reads
    ld      a,11000100b ; wr4 = /64 N1 (see UM008101-0601, pdf page 262)
I believe it should be changed to
    ld      a,11000100b ; wr4 = /64 N1 (see UM008101-0601, page 286-287, [pdf page 306-307])

Ref : In the video "Z80 Retro #16 - Board Testing Pt. VI (Interrupts) at 1:12:30
https://youtu.be/WmhSJg9fJ9U?list=PL3by7evD3F51Cf9QnsAEdgSQ4cz7HQZX5&t=4350

Thanks for creating this series! I'm enjoying following along slowly.

johnwinans, 2023-02-19:
Good catch!  Yeah.  It looks like 262 is an overview.  The details on the later pages make much more sense in this context.
Thanks!

Closed 2023-02-19.

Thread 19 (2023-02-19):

Change the PCB routing around U3, pin 30

johnwinans, 2023-02-19:
Michael Neukam proposed a re-consideration of routing U3 pin-30 (a no-connect in the Retro design) to better address the needs of 28-pin EPROMs.
It appears that the best option would be either a 3-pn header o some solder-jumpers so that pin 30 could be easily connected to either GND or +5V.

johnwinans, 2024-06-21:
I added EZ cut-away net ties pulling pins 1 and 30 to GND to allow bodge-wires to be added without pulling the chip pins back out of the holes.

Closed 2024-06-21.

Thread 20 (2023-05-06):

Documentation of Change of C1, C11, C12 from 0.1uF to 0.47uF on 2063-Z80-4.4.0

dennowiggle, 2023-05-06:
C1, C11, C12 (not C2) around U12 ICL3232CPZ on the 2063-Z80-4.4.0 board changed from 0.1uF to 0.47uF on the schematic and BOM but this is not indicated in the notes on the github page for this version of board, or in the schematic delta/diff file, or in the accompanying video about the changes. It would be nice to update documentation.

I would guess this change is to match the datasheet values for 5.0V operation.

Thanks

johnwinans, 2023-05-06:
Well, the diff images that I recently added are between tags: 4.3.3 and 4.4.0  so the are correct.

But it might have been a good idea to also generate a 4.3.2 to 4.3.3 diff as well... or maybe a 4.3.2 to 4.4.0 diff.

There are also some v3 to v4 diffs in there... that are probably pointless since v4 does not actually exist as a tag.

johnwinans, 2023-05-06:
FYI - I just added V4.3.2-V4.3.3-diffs.sh and the related diff images.  That should make things a bit more clear as to what is going on since you are referring to changes over two different releases rather than changes across only one release.  I would argue that the real problem is that I failed to generate a proper diff when I released v4.3.3.  Sorry.

I also cleaned up the old poorly named script: v3-v4-diffs.sh and renamed it to what it actually does which is to generate a diff between the v3 tag and the HEAD branch... which is not vary useful other than for local testing.

dennowiggle, 2023-05-06:
Thank you for the clarification. I know how much work all of this is, for a hobby.

Closed 2023-05-06.

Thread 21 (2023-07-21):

Document Change to 2063-Z80 Board to Better fit Daughter Cards

dennowiggle, 2023-07-21:
The purpose of this issue is to document a suggestion by John on Discord to allow better fit of daughter cards such as 2068-Z80-TMS9118 and 2065-Z80-programmer.

Currently through hole caps on 2063-Z80 are blocking daughter cards from using the standoff hole in the front right location on daughter cards.

How to address this issue:
   - Remove the following capacitors and place surface mount replacements on the bottom side of  the 2063-Z80 board.
   - This solution has been tested with 0603 and 0805 capacitors on the bottom side of the board. These surface mount capacitors fit nicely across the through hole pads.
   - Locations are :
    - 0.1uF C2, C4, C8
    - 0.47uF C1, C11, C12

It would be nice if the Schematic and README files could document this change.

johnwinans, 2025-08-30:
This should also get into the Retro! manual.

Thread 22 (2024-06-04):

Update specified 74xx logic chips.

thorpej, 2024-06-04:
Per discussion on Discord, it would probably be worth updating the BOM to clarify which 74xx logic families are best for which ICs.  In particular:

- The GPIO-in 74xx244 _does_ need to receive 5V TTL signals, because that will be sufficient to receive the 3V3 CMOS MISO signal from the SD card.  Substituting a 74HCT244 would result in similar performance and lower power consumption over the 74LS244.
- Per episode 10a in the YT playlist, the glue logic for the flash interface could probably benefit from some extra margin.  For this reason, substituting a 74AHC32 for the 74HC32 might be a good choice.  The performance of there other 74xx32 isn't as critical, but specifying both as 74AHC32 simplifies the BOM with basically no cost penalty.
- All other 74xx logic can be HC family -- speed is not a concern for these other applications, and HC is generally preferred over HCT for its reduced vulnerability to noise.

I am planning to build my board this way, and will update this issue with the results.

johnwinans, 2024-07-14:
Just keep the Schmitt on U11 for the reset signal remains important.  Mine glitched like crazy without it.  I could have used a reset chip, but I wanted to keep it on the retro side as reasonable.
Let me know what you think about the rest of the parts.  I'm fine with a new BOM-only release if it is beneficial for the new-comers.
I look forward to hearing about your test results.

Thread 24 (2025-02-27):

Update BOM for 2063-Z80 to include only one line item for 1276-1935-1-ND.

electrosy, 2025-02-27:
I think the two line items for 1276-1935-1-ND can be consolidated in https://github.com/Z80-Retro/2063-Z80/blob/main/2063-Z80.md . Both line items refer to the same part 1276-1935-1-ND for both C17 and C24.

johnwinans, 2025-02-27:
This is a KiCad thing.  The report is auto-generated so hand-editing it will only be frustrating.
They are the same part but the footprints on the PCB are different as far as KiCad is concerned, so they are different.
I will leave this open so the next time I touch the PCB, I will make both footprints the same and this will go away.  Not sure when that will happen.

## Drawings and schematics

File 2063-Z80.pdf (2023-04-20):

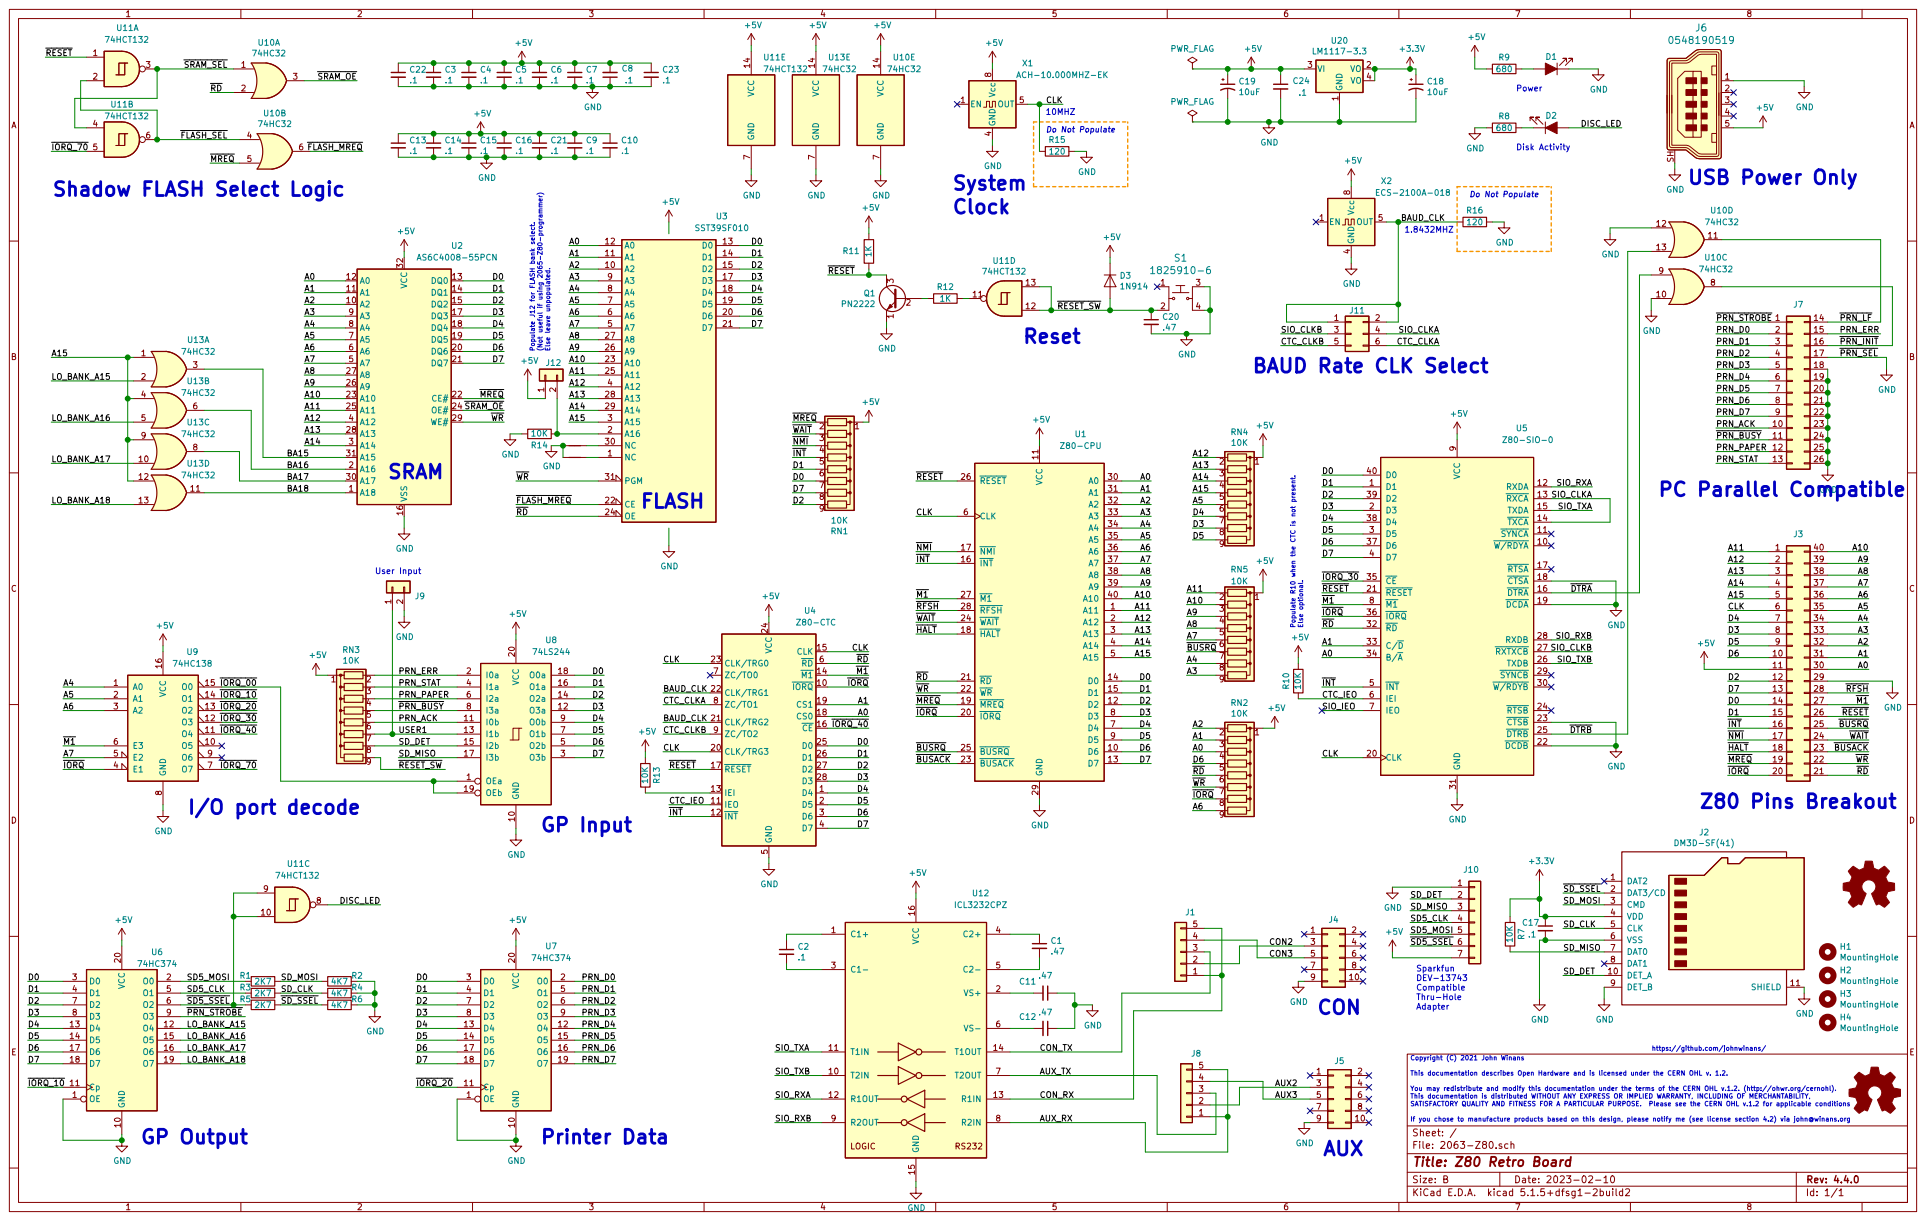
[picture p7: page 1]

Do Not Populate GP Output

Shadow FLASH Select Logic

https://github.com/johnwinans/ System

Clock Populate J12 for FLASH bank select. (Not useful if using 2065-Z80-programmer) Else leave unpopulated.

BAUD Rate CLK Select

5 | PRN_ACK

Sparkfun DEV-13743 Compatible Thru-Hole Adapter

Copyright (C) 2021 John Winans This documentation describes Open Hardware and is licensed under the CERN OHL v. 1.2. You may redistribute and modify this documentation under the terms of the CERN OHL v.1.2. (http://ohwr.org/cernohl). This documentation is distributed WITHOUT ANY EXPRESS OR IMPLIED WARRANTY, INCLUDING OF MERCHANTABILITY, SATISFACTORY QUALITY AND FITNESS FOR A PARTICULAR PURPOSE. Please see the CERN OHL v.1.2 for applicable conditions

If you chose to manufacture products based on this design, please notify me (see license section 4.2) via john@winans.org
File: 2063-Z80.sch Sheet: /
Id: 1/1 Title: Z80 Retro Board

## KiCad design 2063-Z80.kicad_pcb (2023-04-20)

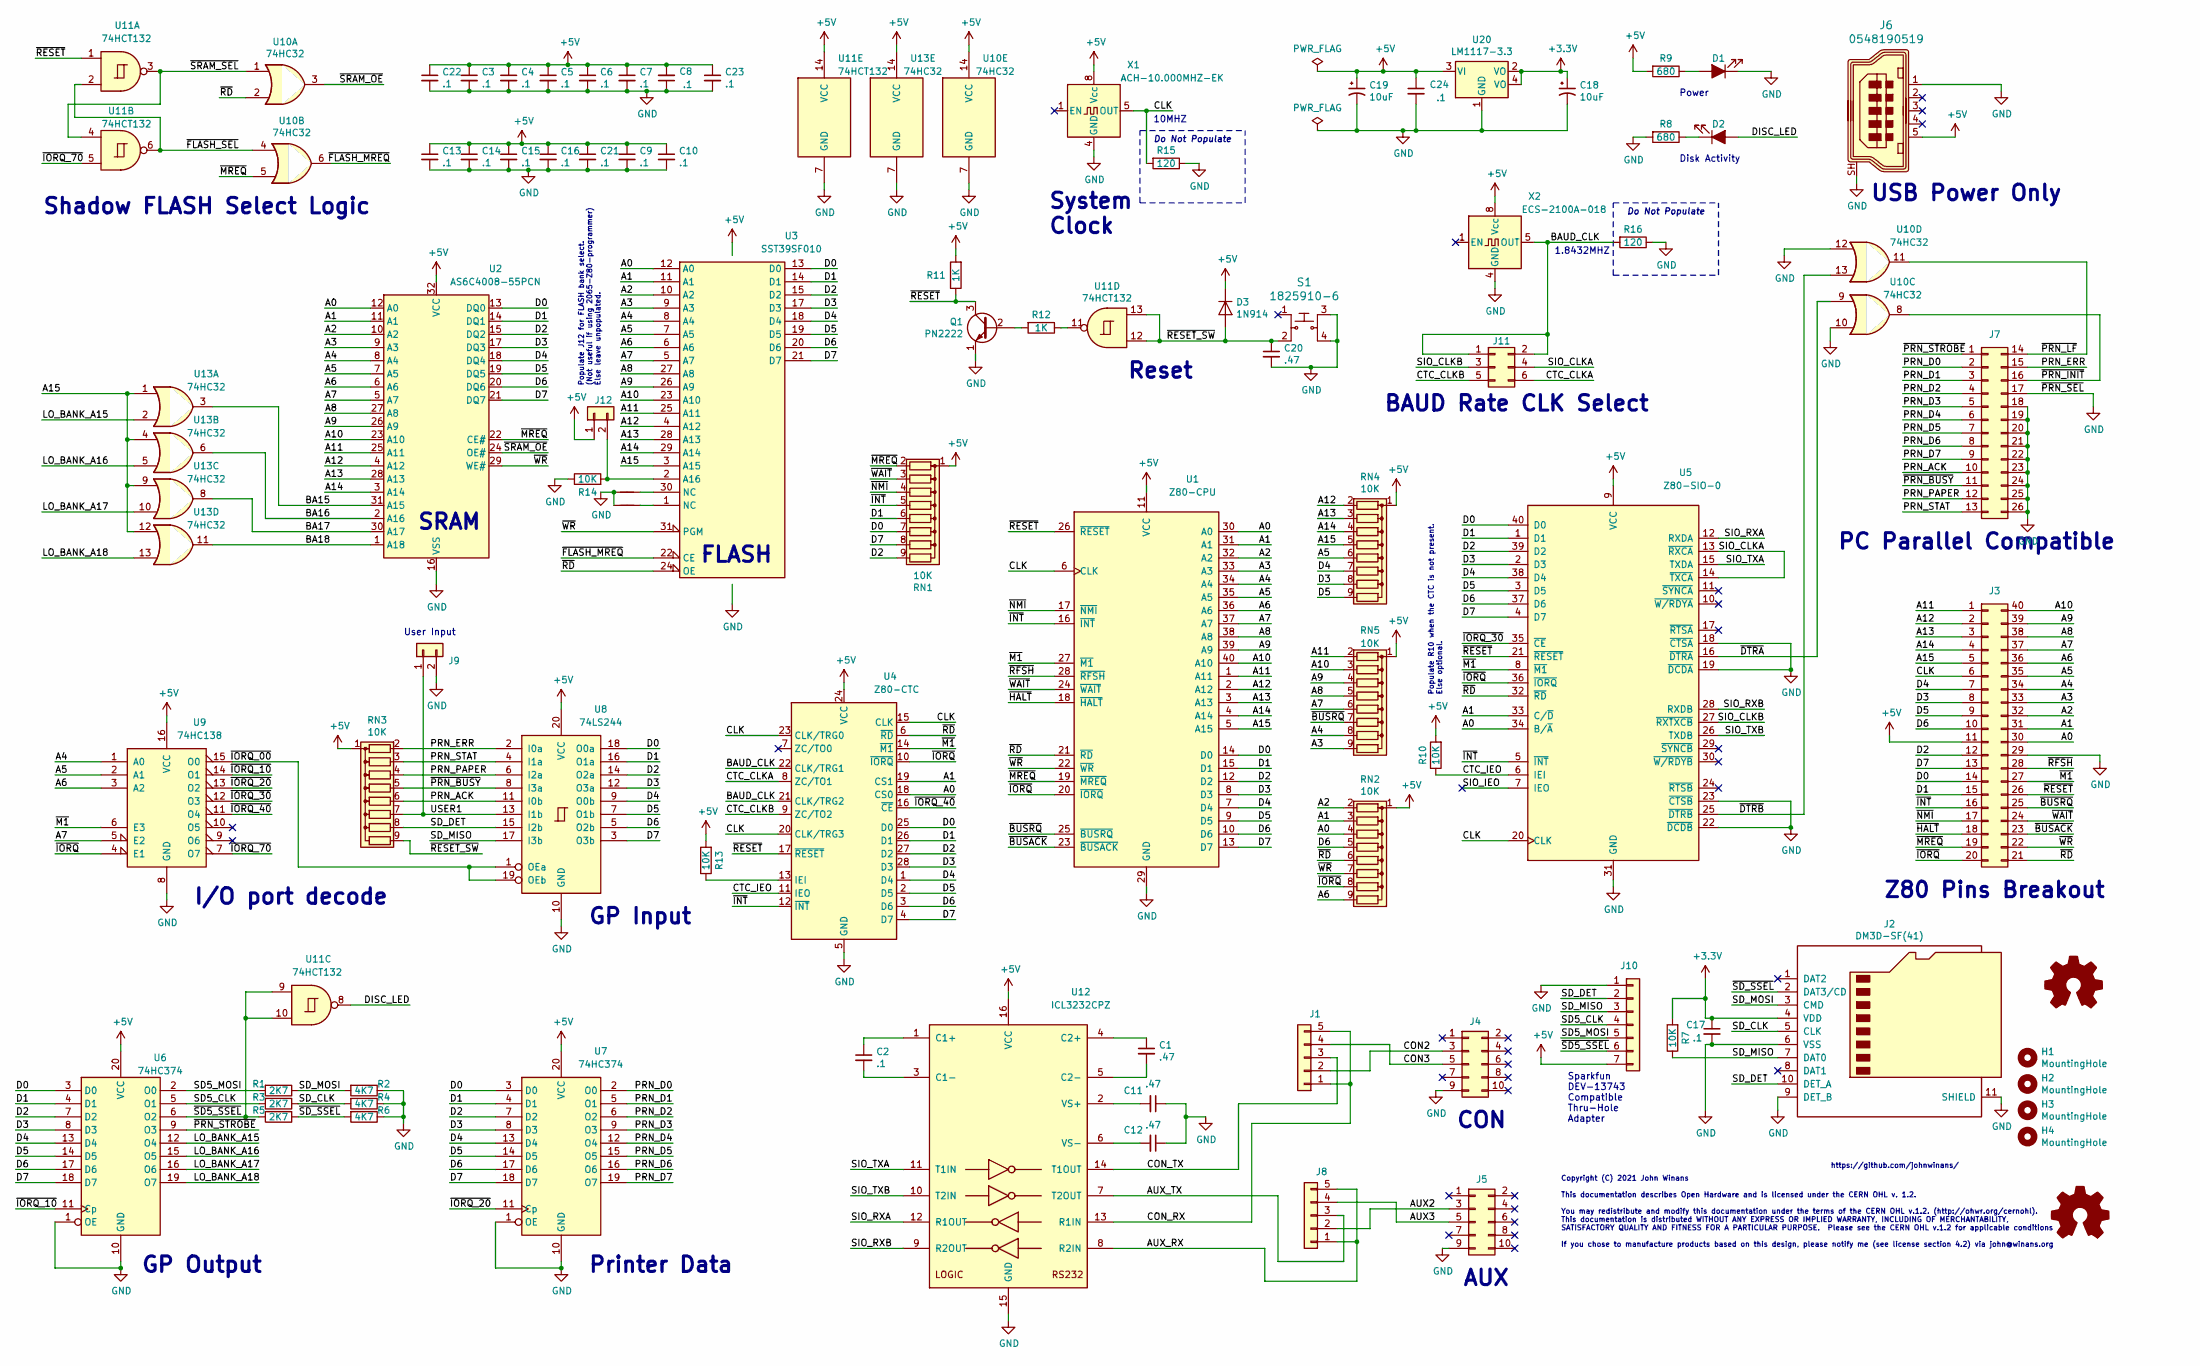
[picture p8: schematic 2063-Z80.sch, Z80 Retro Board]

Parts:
C1, C11, C12, C20: .47; C_Disc_D3.0mm_W2.0mm_P2.50mm; MPN C315C474K5R5TA7303; Digi-Key_PN 399-14039-1-ND
C2, C3, C4, C5, C6, C7, C8, C9, C10, C13, C14, C15, C16, C21, C22, C23: .1; C_Disc_D3.0mm_W2.0mm_P2.50mm; MPN ‎C315C104M5U5TA7303‎; Digi-Key_PN 399-9859-1-ND
C17: .1; C_0805_2012Metric_Pad1.18x1.45mm_HandSolder; MPN CL10B104KB8NNWC; Digi-Key_PN 1276-1935-1-ND
C18: 10uF; C_0805_2012Metric_Pad1.18x1.45mm_HandSolder; MPN CL21A106MQFNNNE; Digi-Key_PN 1276-1298-1-ND
C19: 10uF; CP_Radial_D5.0mm_P2.50mm; MPN ECE-A1EKS100; Digi-Key_PN P975-ND
C24: .1; C_0805_2012Metric_Pad1.15x1.40mm_HandSolder; MPN CL10B104KB8NNWC; Digi-Key_PN 1276-1935-1-ND
D1, D2: LED_ALT; LED_D3.0mm; MPN MV57640; Digi-Key_PN 1080-1122-ND
D3: 1N914; D_DO-35_SOD27_P7.62mm_Horizontal; MPN 1N4148TR; Digi-Key_PN 1N4148FSCT-ND
H1, H2, H3, H4: MountingHole; MountingHole_2.7mm
J1, J8: Conn_01x05; PinHeader_1x05_P2.54mm_Vertical; MPN PRPC005SAAN-RC; Digi-Key_PN S1011EC-05-ND
J2: DM3D-SF(41); microSD_HC_Hirose_DM3D-SF-bigpad; MPN ‎DM3D-SF(41)‎; Digi-Key_PN H126097CT-ND (alternate: 114-00841-68-1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
J3: Conn_02x20; PinHeader_2x20_P2.54mm_Vertical_counterclock; MPN PRPC020DAAN-RC; Digi-Key_PN S2011EC-20-ND
J4, J5: Conn_02x05; PinHeader_2x05_P2.54mm_Vertical; MPN PR20205VBDN; Digi-Key_PN 1849-1002-ND
J6: 0548190519; USB_Mini_B_Female_548190519; MPN 0548190519; Digi-Key_PN A135698-ND
J7: Conn_02x13; PinHeader_2x13_P2.54mm_Top_Bottom; MPN PRPC013DAAN-RC; Digi-Key_PN S2011EC-13-ND
J9, J12: Conn_01x02; PinHeader_1x02_P2.54mm_Vertical; MPN PRPC002SAAN-RC; Digi-Key_PN S1011EC-02-ND
J10: Conn_01x07; PinHeader_1x07_P2.54mm_Vertical; MPN PRPC007SAAN-RC; Digi-Key_PN S1011EC-07-ND
J11: Conn_02x03; PinHeader_2x03_P2.54mm_Vertical; MPN PH2-06-UA; Digi-Key_PN 2057-PH2-06-UA-ND
LOGO1: OSHW_Logo; OSHW-Logo_11.4x12mm_SilkScreen
LOGO2: OSHW_Logo; OSHW-Logo_5.7x6mm_SilkScreen
NT1, NT2: Net-Tie_2; NetTie-2_SMD_Pad0.5mm
Q1: PN2222; TO-92L; MPN PN2222A PBFREE; Digi-Key_PN 1514-PN2222APBFREE-ND
R1, R3, R5: 2K7; R_Axial_DIN0204_L3.6mm_D1.6mm_P5.08mm_Horizontal; MPN ‎CF18JT2K70‎; Digi-Key_PN CF18JT2K70CT-ND
R2, R4, R6: 4K7; R_Axial_DIN0204_L3.6mm_D1.6mm_P5.08mm_Horizontal; MPN ‎CF18JT4K70‎; Digi-Key_PN CF18JT4K70CT-ND
R7, R10, R13, R14: 10K; R_Axial_DIN0204_L3.6mm_D1.6mm_P5.08mm_Horizontal; MPN CF18JT10K0; Digi-Key_PN CF18JT10K0CT-ND
R8, R9: 680; R_Axial_DIN0204_L3.6mm_D1.6mm_P5.08mm_Horizontal; MPN ‎CF18JT680R‎; Digi-Key_PN CF18JT680RCT-ND‎
R11, R12: 1K; R_Axial_DIN0204_L3.6mm_D1.6mm_P5.08mm_Horizontal; MPN ‎CF18JT1K00‎; Digi-Key_PN CF18JT1K00CT-ND‎
R15, R16: 120; R_Axial_DIN0204_L3.6mm_D1.6mm_P5.08mm_Horizontal; MPN CF18JT120R; Digi-Key_PN CF18JT120RCT-ND
RN1, RN2, RN3, RN4, RN5: 10K; R_Array_SIP9; MPN ‎4609X-101-103LF‎; Digi-Key_PN 4609X-101-103LF-ND‎
S1: 1825910-6; Switch_Tactile_THT_6x6mm; MPN 1825910-6; Digi-Key_PN 450-1650-ND
U1: Z80-CPU; DIP-40_W15.24mm_Socket; MPN Z84C0010PEG‎; Digi-Key_PN 269-3898-ND
U2: AS6C4008-55PCN; DIP-32_W15.24mm_Socket; MPN AS6C4008-55PIN; Digi-Key_PN 1450-1178-5-ND‎
U3: SST39SF010; DIP-32_W15.24mm_Socket; MPN SST39SF010A-70-4C-PHE; Digi-Key_PN SST39SF010A-70-4C-PHE-ND‎
U4: Z80-CTC; DIP-28_W15.24mm_Socket; MPN Z84C3010PEG‎; Digi-Key_PN 269-3914-ND
U5: Z80-SIO-0; DIP-40_W15.24mm_Socket; MPN Z84C4010PEG‎; Digi-Key_PN 269-5062-ND‎
U6, U7: 74HC374; DIP-20_W7.62mm_Socket; MPN CD74HC374E; Digi-Key_PN 296-12806-5-ND
U8: 74LS244; DIP-20_W7.62mm_Socket; MPN SN74LS244NE4; Digi-Key_PN 296-36148-5-ND
U9: 74HC138; DIP-16_W7.62mm_Socket; MPN SN74HC138AN; Digi-Key_PN 296-SN74HC138AN-ND
U10, U13: 74HC32; DIP-14_W7.62mm_Socket; MPN CD74HC32E; Digi-Key_PN 296-12803-5-ND
U11: 74HCT132; DIP-14_W7.62mm_Socket; MPN CD74HCT132E; Digi-Key_PN 296-2090-5-ND
U12: ICL3232CPZ; DIP-16_W7.62mm_Socket; MPN ‎ICL3232CPZ‎; Digi-Key_PN ICL3232CPZ-ND‎
U20: LM1117-3.3; SOT-223; MPN NCP1117ST33T3G; Digi-Key_PN NCP1117ST33T3GOSCT-ND
X1: ACH-10.000MHZ-EK; Oscillator_DIP-8_combo; MPN ACH-10.000MHZ-EK; Digi-Key_PN 535-9167-5-ND
X2: ECS-2100A-018; Oscillator_DIP-8_combo; MPN ‎ECS-2100A-018‎; Digi-Key_PN XC231-ND‎

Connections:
+3V3: C17.1, C18.1, J2.4 (VDD), R7.2, U20.2 (VO), U20.4 (VO)
+5V: C3.1, C4.1, C5.1, C6.1, C7.1, C8.2, C9.1, C10.1, C13.1, C14.1, C15.1, C16.1, C19.1, C21.1, C22.1, C23.1, C24.1, D3.1 (K), J3.11, J6.5, J10.7, J12.1, R9.2, R10.2, R11.2, R13.2, RN1.1 (common), RN2.1 (common), RN3.1 (common), RN4.1 (common), RN5.1 (common), U1.11 (VCC), U2.32 (VCC), U3.32 (VCC), U4.24 (VCC), U5.9 (VCC), U6.20 (VCC), U7.20 (VCC), U8.20 (VCC), U9.16 (VCC), U10.14 (VCC), U11.14 (VCC), U12.16 (VCC), U13.14 (VCC), U20.3 (VI), X1.8 (Vcc), X2.8 (Vcc)
/A0: J3.30, RN2.4 (R3), U1.30 (A0), U2.12 (A0), U3.12 (A0), U4.18 (CS0), U5.34 (B/~A)
/A1: J3.31, RN2.3 (R2), U1.31 (A1), U2.11 (A1), U3.11 (A1), U4.19 (CS1), U5.33 (C/~D)
/A2: J3.32, RN2.2 (R1), U1.32 (A2), U2.10 (A2), U3.10 (A2)
/A3: J3.33, RN5.9 (R8), U1.33 (A3), U2.9 (A3), U3.9 (A3)
/A4: J3.34, RN5.8 (R7), U1.34 (A4), U2.8 (A4), U3.8 (A4), U9.1 (A0)
/A5: J3.35, RN4.6 (R5), U1.35 (A5), U2.7 (A5), U3.7 (A5), U9.2 (A1)
/A6: J3.36, RN2.9 (R8), U1.36 (A6), U2.6 (A6), U3.6 (A6), U9.3 (A2)
/A7: J3.37, RN5.6 (R5), U1.37 (A7), U2.5 (A7), U3.5 (A7), U9.5 (E2)
/A8: J3.38, RN5.5 (R4), U1.38 (A8), U2.27 (A8), U3.27 (A8)
/A9: J3.39, RN5.4 (R3), U1.39 (A9), U2.26 (A9), U3.26 (A9)
/A10: J3.40, RN5.3 (R2), U1.40 (A10), U2.23 (A10), U3.23 (A10)
/A11: J3.1, RN5.2 (R1), U1.1 (A11), U2.25 (A11), U3.25 (A11)
/A12: J3.2, RN4.2 (R1), U1.2 (A12), U2.4 (A12), U3.4 (A12)
/A13: J3.3, RN4.3 (R2), U1.3 (A13), U2.28 (A13), U3.28 (A13)
/A14: J3.4, RN4.4 (R3), U1.4 (A14), U2.3 (A14), U3.29 (A14)
/A15: J3.5, RN4.5 (R4), U1.5 (A15), U3.3 (A15), U13.1, U13.4, U13.9, U13.12
/AUX2: J5.3, J8.2
/AUX3: J5.5, J8.4
/AUX_RX: J8.1, J8.5, U12.8 (R2IN)
/AUX_TX: J8.3, U12.7 (T2OUT)
/BA15: U2.31 (A15), U13.3
/BA16: U2.2 (A16), U13.6
/BA17: U2.30 (A17), U13.8
/BA18: U2.1 (A18), U13.11
/BAUD_CLK: J11.1, J11.2, R16.2, U4.21 (CLK/TRG2), U4.22 (CLK/TRG1), X2.5 (OUT)
/CLK: J3.6, R15.2, U1.6 (CLK), U4.15 (CLK), U4.20 (CLK/TRG3), U4.23 (CLK/TRG0), U5.20 (CLK), X1.5 (OUT)
/CON2: J1.2, J4.3
/CON3: J1.4, J4.5
/CON_RX: J1.1, J1.5, U12.13 (R1IN)
/CON_TX: J1.3, U12.14 (T1OUT)
/CTC_CLKA: J11.6, U4.8 (ZC/TO1)
/CTC_CLKB: J11.5, U4.9 (ZC/TO2)
/CTC_IEO: R10.1, U4.11 (IEO), U5.6 (IEI)
/D0: J3.14, RN1.7 (R6), U1.14 (D0), U2.13 (DQ0), U3.13 (D0), U4.25 (D0), U5.40 (D0), U6.3 (D0), U7.3 (D0), U8.18 (O0a)
/D1: J3.15, RN1.6 (R5), U1.15 (D1), U2.14 (DQ1), U3.14 (D1), U4.26 (D1), U5.1 (D1), U6.4 (D1), U7.4 (D1), U8.16 (O1a)
/D2: J3.12, RN1.9 (R8), U1.12 (D2), U2.15 (DQ2), U3.15 (D2), U4.27 (D2), U5.39 (D2), U6.7 (D2), U7.7 (D2), U8.14 (O2a)
/D3: J3.8, RN4.8 (R7), U1.8 (D3), U2.17 (DQ3), U3.17 (D3), U4.28 (D3), U5.2 (D3), U6.8 (D3), U7.8 (D3), U8.12 (O3a)
/D4: J3.7, RN4.7 (R6), U1.7 (D4), U2.18 (DQ4), U3.18 (D4), U4.1 (D4), U5.38 (D4), U6.13 (D4), U7.13 (D4), U8.9 (O0b)
/D5: J3.9, RN4.9 (R8), U1.9 (D5), U2.19 (DQ5), U3.19 (D5), U4.2 (D5), U5.3 (D5), U6.14 (D5), U7.14 (D5), U8.7 (O1b)
/D6: J3.10, RN2.5 (R4), U1.10 (D6), U2.20 (DQ6), U3.20 (D6), U4.3 (D6), U5.37 (D6), U6.17 (D6), U7.17 (D6), U8.5 (O2b)
/D7: J3.13, RN1.8 (R7), U1.13 (D7), U2.21 (DQ7), U3.21 (D7), U4.4 (D7), U5.4 (D7), U6.18 (D7), U7.18 (D7), U8.3 (O3b)
/DISC_LED: D2.2 (A), U11.8
/LO_BANK_A15: U6.12 (O4), U13.2
/LO_BANK_A16: U6.15 (O5), U13.5
/LO_BANK_A17: U6.16 (O6), U13.10
/LO_BANK_A18: U6.19 (O7), U13.13
/PRN_ACK: J7.10, RN3.6 (R5), U8.11 (I0b)
/PRN_D0: J7.2, U7.2 (O0)
/PRN_D1: J7.3, U7.5 (O1)
/PRN_D2: J7.4, U7.6 (O2)
/PRN_D3: J7.5, U7.9 (O3)
/PRN_D4: J7.6, U7.12 (O4)
/PRN_D5: J7.7, U7.15 (O5)
/PRN_D6: J7.8, U7.16 (O6)
/PRN_D7: J7.9, U7.19 (O7)
/PRN_ERR: J7.15, RN3.2 (R1), U8.2 (I0a)
/PRN_PAPER: J7.12, RN3.4 (R3), U8.6 (I2a)
/PRN_STAT: J7.13, RN3.3 (R2), U8.4 (I1a)
/SD5_CLK: J10.4, R3.2, U6.5 (O1)
/SD5_MOSI: J10.5, R1.2, U6.2 (O0)
/SD_CLK: J2.5 (CLK), R3.1, R4.2
/SD_DET: J2.10 (DET_A), J10.2, RN3.8 (R7), U8.15 (I2b)
/SD_MISO: J2.7 (DAT0), J10.3, R7.1, U8.17 (I3b)
/SD_MOSI: J2.3 (CMD), R1.1, R2.2
/SIO_CLKA: J11.4, U5.13 (~RXCA), U5.14 (~TXCA)
/SIO_CLKB: J11.3, U5.27 (~RXTXCB)
/SIO_IEO: U5.7 (IEO)
/SIO_RXA: U5.12 (RXDA), U12.12 (R1OUT)
/SIO_RXB: U5.28 (RXDB), U12.9 (R2OUT)
/SIO_TXA: U5.15 (TXDA), U12.11 (T1IN)
/SIO_TXB: U5.26 (TXDB), U12.10 (T2IN)
/USER1: J9.1, RN3.7 (R6), U8.13 (I1b)
/~BUSACK: J3.23, U1.23 (~BUSACK~)
/~BUSRQ: J3.25, RN5.7 (R6), U1.25 (~BUSRQ~)
/~DTRA: U5.16 (~DTRA), U10.9
/~DTRB: U5.25 (~DTRB), U10.13
/~FLASH_MREQ: U3.22 (CE), U10.6
/~FLASH_SEL: U10.4, U11.2, U11.6
/~HALT: J3.18, U1.18 (~HALT~)
/~INT: J3.16, RN1.5 (R4), U1.16 (~INT~), U4.12 (~INT), U5.5 (~INT)
/~IORQ: J3.20, RN2.8 (R7), U1.20 (~IORQ~), U4.10 (~IORQ), U5.36 (~IORQ), U9.4 (E1)
/~IORQ_00: U8.1 (OEa), U8.19 (OEb), U9.15 (O0)
/~IORQ_10: U6.11 (Cp), U9.14 (O1)
/~IORQ_20: U7.11 (Cp), U9.13 (O2)
/~IORQ_30: U5.35 (~CE), U9.12 (O3)
/~IORQ_40: U4.16 (~CE), U9.11 (O4)
/~IORQ_70: U9.7 (O7), U11.5
/~M1: J3.27, U1.27 (~M1~), U4.14 (~M1), U5.8 (~M1), U9.6 (E3)
/~MREQ: J3.19, RN1.2 (R1), U1.19 (~MREQ~), U2.22 (CE#), U10.5
/~NMI: J3.17, RN1.4 (R3), U1.17 (~NMI~)
/~PRN_BUSY: J7.11, RN3.5 (R4), U8.8 (I3a)
/~PRN_INIT: J7.16, U10.8
/~PRN_LF: J7.14, U10.11
/~PRN_STROBE: J7.1, U6.9 (O3)
/~RD: J3.21, RN2.6 (R5), U1.21 (~RD~), U3.24 (OE), U4.6 (~RD), U5.32 (~RD), U10.2
/~RESET: J3.26, Q1.3 (C), R11.1, U1.26 (~RESET~), U4.17 (~RESET), U5.21 (~RESET), U11.1
/~RESET_SW: C20.1, D3.2 (A), RN3.9 (R8), S1.2, U11.12, U11.13
/~RFSH: J3.28, U1.28 (~RFSH~)
/~SD5_SSEL: J10.6, R5.2, U6.6 (O2), U11.9, U11.10
/~SD_SSEL: J2.2 (DAT3/CD), R5.1, R6.2
/~SRAM_OE: U2.24 (OE#), U10.3
/~SRAM_SEL: U10.1, U11.3, U11.4
/~WAIT: J3.24, RN1.3 (R2), U1.24 (~WAIT~)
/~WR: J3.22, RN2.7 (R6), U1.22 (~WR~), U2.29 (WE#), U3.31 (PGM)
GND: C3.2, C4.2, C5.2, C6.2, C7.2, C8.1, C9.2, C10.2, C11.1, C12.1, C13.2, C14.2, C15.2, C16.2, C17.2, C18.2, C19.2, C20.2, C21.2, C22.2, C23.2, C24.2, D1.1 (K), J2.6 (VSS), J2.9 (DET_B), J2.11 (SHIELD), J3.29, J4.9, J5.9, J6.1, J6.SH, J7.17, J7.18, J7.19, J7.20, J7.21, J7.22, J7.23, J7.24, J7.25, J7.26, J9.2, J10.1, NT1.1, NT2.1, Q1.1 (E), R2.1, R4.1, R6.1, R8.2, R14.1, R15.1, R16.1, S1.3, S1.4, U1.29 (GND), U2.16 (VSS), U3.16 (GND), U4.5 (GND), U5.18 (~CTSA), U5.19 (~DCDA), U5.22 (~DCDB), U5.23 (~CTSB), U5.31 (GND), U6.1 (OE), U6.10 (GND), U7.1 (OE), U7.10 (GND), U8.10 (GND), U9.8 (GND), U10.7 (GND), U10.10, U10.12, U11.7 (GND), U12.15 (GND), U13.7 (GND), U20.1 (GND), X1.4 (GND), X2.4 (GND)
unnamed: C1.1, U12.4 (C2+)
unnamed: C1.2, U12.5 (C2-)
unnamed: C2.1, U12.1 (C1+)
unnamed: C2.2, U12.3 (C1-)
unnamed: C11.2, U12.2 (VS+)
unnamed: C12.2, U12.6 (VS-)
unnamed: D1.2 (A), R9.1
unnamed: D2.1 (K), R8.1
unnamed: J12.2, R14.2, U3.2 (A16)
unnamed: NT1.2, U3.30 (NC)
unnamed: NT2.2, U3.1 (NC)
unnamed: Q1.2 (B), R12.2
unnamed: R12.1, U11.11
unnamed: R13.1, U4.13 (IEI)

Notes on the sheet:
Disk Activity
Power
USB Power Only
Z80 Pins Breakout
Shadow FLASH Select Logic
FLASH
SRAM
GP Input
GP Output
Printer Data
PC Parallel Compatible
1.8432MHZ
I/O port decode
CON
AUX
Copyright (C) 2021 John Winans This documentation describes Open Hardware and is licensed under the CERN OHL v. 1.2. You may redistribute and modify this documentation under the terms of the CERN OHL v.1.2. (http://ohwr.org/cernohl). This documentation is distributed WITHOUT ANY EXPRESS OR IMPLIED 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
Reset
10MHZ
https://github.com/johnwinans/
Sparkfun DEV-13743 Compatible Thru-Hole Adapter
BAUD Rate CLK Select
System Clock
Populate R10 when the CTC is not present. Else optional.
User Input
Populate J12 for FLASH bank select. (Not useful if using 2065-Z80-programmer) Else leave unpopulated.
Do Not Populate

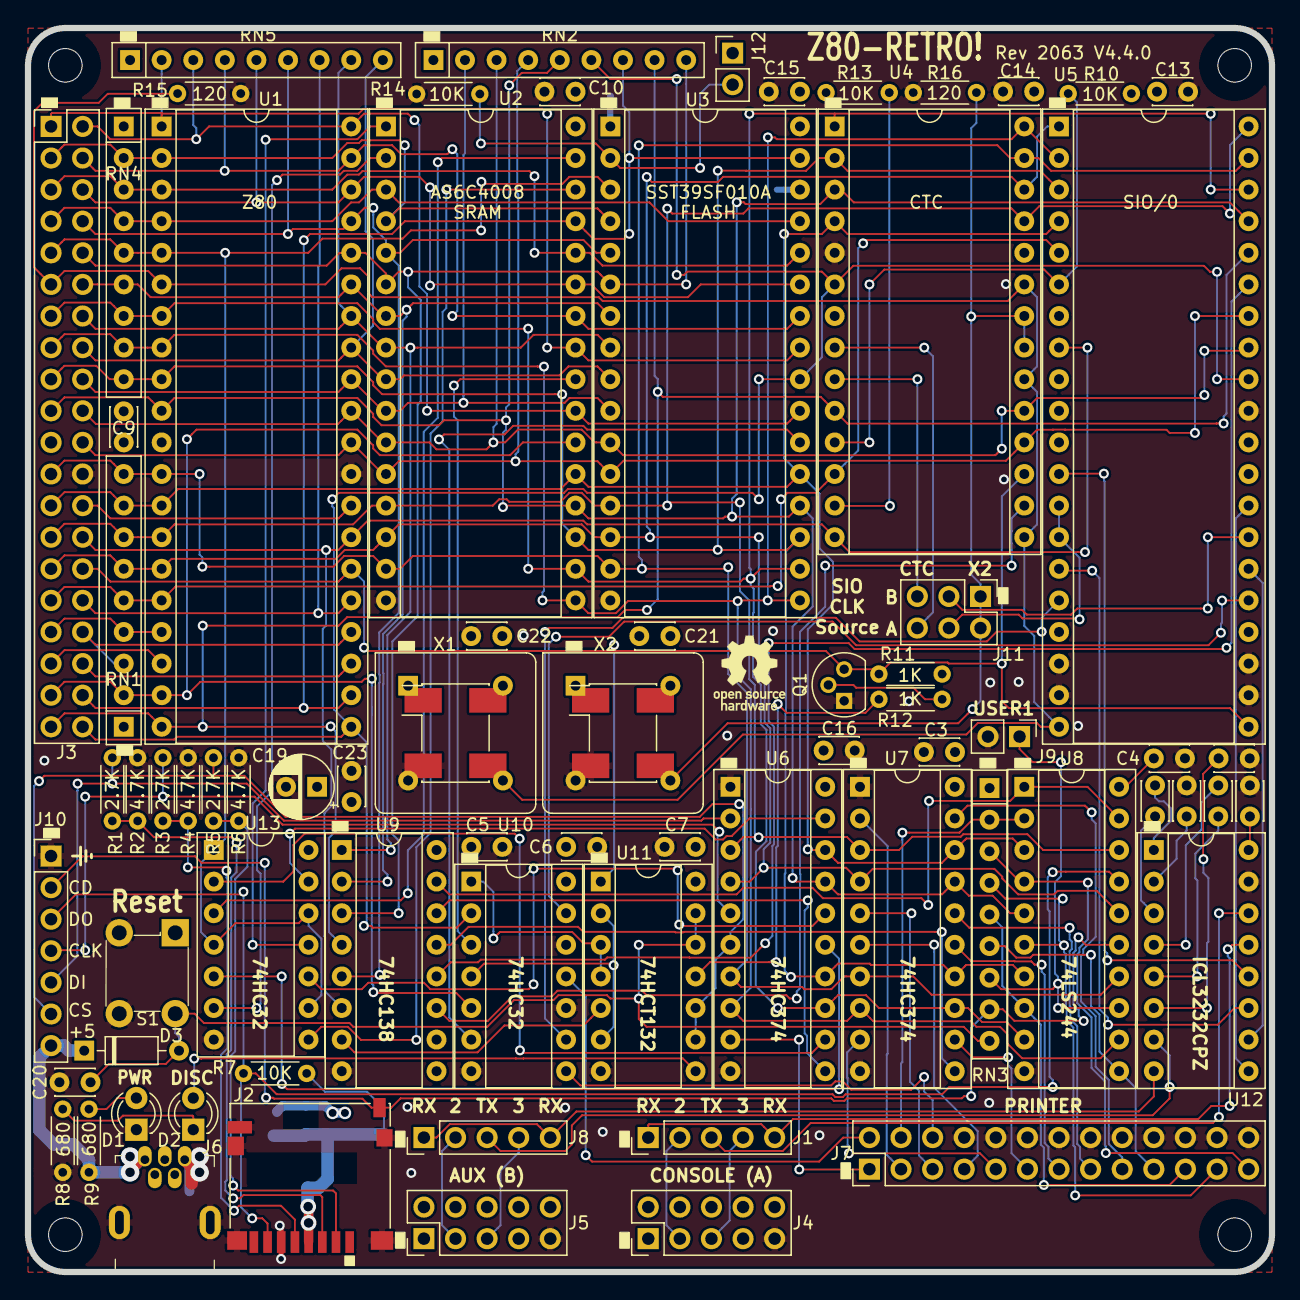
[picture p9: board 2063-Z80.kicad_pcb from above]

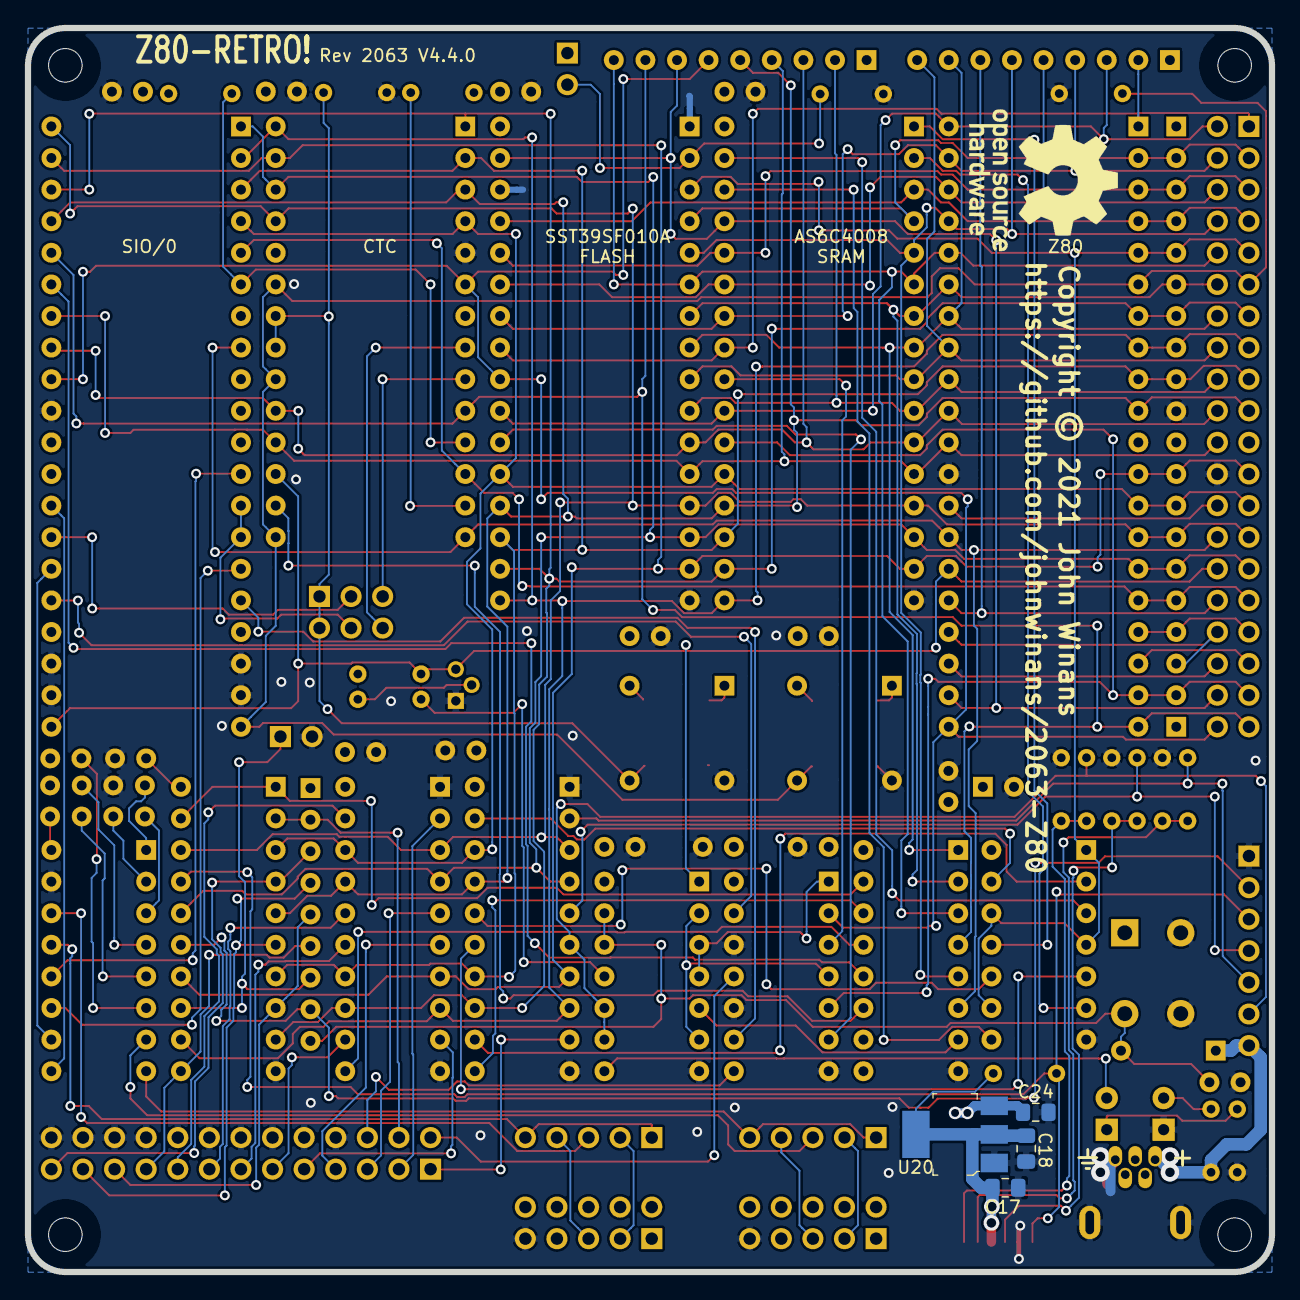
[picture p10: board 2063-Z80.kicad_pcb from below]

Board: 4 copper layers, 100.0 x 100.0 mm, 86 parts (7 on the bottom side), 120 nets.

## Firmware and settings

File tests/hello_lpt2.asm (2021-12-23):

;****************************************************************************
;
;    Copyright (C) 2021 John Winans
;
;    This library is free software; you can redistribute it and/or
;    modify it under the terms of the GNU Lesser General Public
;    License as published by the Free Software Foundation; either
;    version 2.1 of the License, or (at your option) any later version.
;
;    This library is distributed in the hope that it will be useful,
;    but WITHOUT ANY WARRANTY; without even the implied warranty of
;    MERCHANTABILITY or FITNESS FOR A PARTICULAR PURPOSE.  See the GNU
;    Lesser General Public License for more details.
;
;    You should have received a copy of the GNU Lesser General Public
;    License along with this library; if not, write to the Free Software
;    Foundation, Inc., 51 Franklin Street, Fifth Floor, Boston, MA 02110-1301
;    USA
;
;****************************************************************************

; Write gaudy banners to the printer in a loop. 

include 'io.asm'

stacktop:   equ 0   ; end of RAM + 1

    ;###################################################
    ; NOTE THAT THE SRAM IS NOT READABLE AT THIS POINT
    ;###################################################

    ; Select SRAM low bank 0, idle the SD card, and idle printer signals
    ld  a,gpio_out_sd_mosi|gpio_out_sd_ssel|gpio_out_sd_clk|gpio_out_prn_stb
    out (gpio_out),a

    ; Copy the FLASH into the SRAM by reading every byte and 
    ; writing it back into the same address.
    ld  hl,0
    ld  de,0
    ld  bc,_end
    ldir

    ; Disable the FLASH and run from SRAM only from this point on.
    in  a,(flash_disable)   ; Dummy-read this port to disable the FLASH.

    ;###################################################
    ; STARTING HERE, WE ARE RUNNING FROM RAM
    ;###################################################

    ld      sp,stacktop

    call    sioa_init
    call    lpt_init

    ld      hl,rx80_compress
    ld      bc,rx80_compress_len
    call    print_str

waste_paper:
    ld      hl,msg
    ld      bc,msg_len
    call    print_str
    jp      waste_paper


halt_loop:
    halt
    jp      halt_loop


rx80_compress:
    db  0x0f
rx80_compress_len:  equ $-rx80_compress



msg:

if 0
    db  "               ________   ___    ____      _             _   ____       _       _              _____         _                 \r\n"
    db  "              |__  ( _ ) / _ \\  |  _ \\ ___| |_ _ __ ___ | | |  _ \\ _ __(_)_ __ | |_ ___ _ __  |_   _|__  ___| |_               \r\n"
    db  " _____ _____    / // _ \\| | | | | |_) / _ \\ __| '__/ _ \\| | | |_) | '__| | '_ \\| __/ _ \\ '__|   | |/ _ \\/ __| __|  _____ _____ \r\n"
    db  "|_____|_____|  / /| (_) | |_| | |  _ <  __/ |_| | | (_) |_| |  __/| |  | | | | | ||  __/ |      | |  __/\\__ \\ |_  |_____|_____|\r\n"
    db  "              /____\\___/ \\___/  |_| \\_\\___|\\__|_|  \\___/(_) |_|   |_|  |_|_| |_|\\__\\___|_|      |_|\\___||___/\\__|              \r\n"
    db  "\r\n"
endif

if 0
    db  "\r\n"
    db  "#######  #####    ###      ######                             ###    ######                           #######                     \r\n"
    db  "     #  #     #  #   #     #     # ###### ##### #####   ####  ###    #     # #####  # #    # #####       #    ######  ####  ##### \r\n"
    db  "    #   #     # #     #    #     # #        #   #    # #    # ###    #     # #    # # ##   #   #         #    #      #        #   \r\n"
    db  "   #     #####  #     #    ######  #####    #   #    # #    #  #     ######  #    # # # #  #   #         #    #####   ####    #   \r\n"
    db  "  #     #     # #     #    #   #   #        #   #####  #    #        #       #####  # #  # #   #         #    #           #   #   \r\n"
    db  " #      #     #  #   #     #    #  #        #   #   #  #    # ###    #       #   #  # #   ##   #         #    #      #    #   #   \r\n"
    db  "#######  #####    ###      #     # ######   #   #    #  ####  ###    #       #    # # #    #   #         #    ######  ####    #   \r\n"
    db  "\r\n"
endif

if 1
    ; Mostly overstrike to exercise the print carriage w/o wasting paper.
    db  "\r"
    db  "#######  #####    ###      ######                             ###    ######                           #######                     \r"
    db  "     #  #     #  #   #     #     # ###### ##### #####   ####  ###    #     # #####  # #    # #####       #    ######  ####  ##### \r"
    db  "    #   #     # #     #    #     # #        #   #    # #    # ###    #     # #    # # ##   #   #         #    #      #        #   \r"
    db  "   #     #####  #     #    ######  #####    #   #    # #    #  #     ######  #    # # # #  #   #         #    #####   ####    #   \r"
    db  "  #     #     # #     #    #   #   #        #   #####  #    #        #       #####  # #  # #   #         #    #           #   #   \r"
    db  " #      #     #  #   #     #    #  #        #   #   #  #    # ###    #       #   #  # #   ##   #         #    #      #    #   #   \r"
    db  "#######  #####    ###      #     # ######   #   #    #  ####  ###    #       #    # # #    #   #         #    ######  ####    #   \r"
    db  "\r\n"
endif
if 1
    db  "\r..............."
    db  "\r               ..............."
    db  "\r---------------"
    db  "\r               ---------------"
    db  "\r_______________"
    db  "\r               _______________"
    db  "\r!!!!!!!!!!!!!!!"
    db  "\r               !!!!!!!!!!!!!!!"
    db  "\r<<<<<<<<<<<<<<<"
    db  "\r               <<<<<<<<<<<<<<<"
    db  "\r>>>>>>>>>>>>>>>"
    db  "\r               >>>>>>>>>>>>>>>"
    db  "\r000000000000000"
    db  "\r               000000000000000"
    db  "\r#########"
    db  "\r000000000"
    db  "\r@@@@@@@@@"
    db  "\r\n"
endif
msg_len: equ $-msg

;#############################################################################
; Write BC bytes from memory at address in HL
;#############################################################################
print_str:
    push    bc
    ld      c,(hl)
    call    lpt_tx
    inc     hl
    pop     bc
    dec     bc
    ld      a,b
    or      c
    jr      nz,print_str
    ret


include 'lpt.asm'
include 'sio.asm'
include 'hexdump.asm'

;#############################################################################
; A copy of the state of the GPIO output port
;#############################################################################
gpio_out_cache:
    db  gpio_out_sd_mosi|gpio_out_sd_ssel|gpio_out_sd_clk|gpio_out_prn_stb

_end:

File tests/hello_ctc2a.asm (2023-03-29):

;****************************************************************************
;
;    Copyright (C) 2021 John Winans
;
;    This library is free software; you can redistribute it and/or
;    modify it under the terms of the GNU Lesser General Public
;    License as published by the Free Software Foundation; either
;    version 2.1 of the License, or (at your option) any later version.
;
;    This library is distributed in the hope that it will be useful,
;    but WITHOUT ANY WARRANTY; without even the implied warranty of
;    MERCHANTABILITY or FITNESS FOR A PARTICULAR PURPOSE.  See the GNU
;    Lesser General Public License for more details.
;
;    You should have received a copy of the GNU Lesser General Public
;    License along with this library; if not, write to the Free Software
;    Foundation, Inc., 51 Franklin Street, Fifth Floor, Boston, MA 02110-1301
;    USA
;
;****************************************************************************

; Test proggie for the CTC w/support for the SIO.
; CTC runs channel 3 with IRQs to implement an uptime timer.
; SIO runs in polled mode.
; Use J11-A to select between x2 (115200) and the CTC zc/to signal.

include 'io.asm'

stacktop:   equ 0   ; end of RAM + 1

    ;###################################################
    ; NOTE THAT THE SRAM IS NOT READABLE AT THIS POINT
    ;###################################################

    ; Select SRAM low bank 0, idle the SD card, and idle printer signals
    ld  a,gpio_out_sd_mosi|gpio_out_sd_ssel|gpio_out_prn_stb
    out (gpio_out),a

    ; Copy the FLASH into the SRAM by reading every byte and 
    ; writing it back into the same address.
    ld  hl,0
    ld  de,0
    ld  bc,_end
    ldir

    ; Disable the FLASH and run from SRAM only from this point on.
    in  a,(flash_disable)   ; Dummy-read this port to disable the FLASH.

    ;###################################################
    ; STARTING HERE, WE ARE RUNNING FROM RAM
    ;###################################################

    ld      sp,stacktop

    ; set mode 2 interrupts & load the vector table address into I
    im      2
    ld      a,vectab/256    ; A = MSB of the vectab address
    ld      i,a 

    ld      a,vectab_ctc-vectab
    call    init_ctc_irq

    call    init_ctc_3

    ; CTC values assuming the SIO is running in /64 mode
;   ld      c,3             ; 9600 bps
;   ld      c,6             ; 4800 bps
;   ld      c,12            ; 2400 bps
;   ld      c,24            ; 1200 bps
    ld      c,96            ; 300 bps
    call    init_ctc_1

    call    sioa_init

if 1
    ; An ugly hack to tweak the bit-rate divisor on SIO port A to /64
    ld      a,00000100b ; select reg 4
    out     (sio_ac),a
    ld      a,11000100b ; wr4 = /64 N1 (see UM008101-0601, page 286-287, [pdf page 306-307])
    out     (sio_ac),a
endif

    ei

    ; skip a line
    ld      b,'\r'          
    call    sioa_tx_char
    ld      b,'\n'
    call    sioa_tx_char

if 0
    ; Dump the memory containing this code
    ld      hl,0            ; start address
    ld      bc,_end         ; how many bytes to print
    ld      e,1             ; fancy format
    call    hexdump
endif




;##########################################################################
; Enter a spin-loop that prints the time as it advances.
;##########################################################################

if 0

loop:
    halt                    ; do nothing until an IRQ or RESET

    ; The only way to get here is if an IRQ has occurred...

if 1
    ; print on modulo N of the uptime
    ld      hl,(uptime)
    ld      a,l
    and     0x3f
    jp      nz,loop
endif

    ld      hl,uptime   ; start address
    ld      bc,0x0004   ; how many bytes to print
    ld      e,0         ; do not fancy format

    call    hexdump     ; XXX This COULD be interrupted!
                        ; XXX What if printing takes longer than the IRQ period????

    jp      loop



else 


; This is an alternate HALT-loop that is better than the above logic...
; BUT still not as good as it could be.  In an optimal situation, there
; would be some sort of sempahore logic used by the IRQ handler and this 
; loop.  Simply using halt here could get confused by other IRQs that the 
; system might be processing!

safeloop:
    ei
    halt                ; do nothing until an IRQ or RESET

    di
if 1
    ; print on modulo N of the uptime
    ld      hl,(uptime)
    ld      a,l
    and     0x3f
    jp      nz,safeloop
endif

    ; Copy the uptime counter with IRQs disables so we get a clean copy!
    ;ld      hl,(uptime)
    ld      (safeuptime),hl
    ld      hl,(uptime+2)
    ld      (safeuptime+2),hl
    ei

    ld      hl,safeuptime   ; start address
    ld      bc,0x0004       ; how many bytes to print
    ld      e,0             ; do not fancy format
    call    hexdump     

    jp      safeloop


safeuptime:
    dw  0,0

endif



include 'ctc.asm'
include 'sio.asm'
include 'hexdump.asm'

;#############################################################################
;#############################################################################
; The mode 2 IRQ vector table 
; The table must start at an even address since CTC vector is always even.
; It /can/ be different than a 256-byte boundary...
;   but the vector offsets are more obvious when it is.

if $&0xff           ; if not already at an address that is a multiple of 0x100
    ds      0x100-($&0xff),0xff  ; add padding to align to a 0x100 boundary
endif

vectab:
vectab_ctc:     ; vectab_ctc-vectab MUST be a multiple of 8 due to CTC requirements
    dw      irq_ctc_0
    dw      irq_ctc_1
    dw      irq_ctc_2
    dw      irq_ctc_3


_end:

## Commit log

2021-08-20 First release.
    [2063-Z80-B_Cu.gbl, 2063-Z80-B_Mask.gbs, 2063-Z80-B_Paste.gbp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]
2021-08-24 BOM updates.
    [2063-Z80.sch]
2021-09-04 Add jumpers for getting the SIO baud rate clock direct from X2 (EZ-bypass the CTC) Missing white-slug on J10 Show R8 & R9 as 680 ohms on silkscreen Change part number of the NAND gate to 74HCT132E (S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
    [2063-Z80.kicad_pcb, 2063-Z80.sch]
2021-09-06 Add another 74LS32 for 512K memory support. Move 3.3v reg on back under the SD card. Use surface-mount caps for 3.3v power. Add alternate SMT footprints for X1 and X2.
    [2063-Z80-B_Cu.gbl, 2063-Z80-B_Mask.gbs, 2063-Z80-B_Paste.gbp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]
2021-09-07 Update the PCB picture.
2021-09-07 Add part name to silk for U13.
    [2063-Z80.kicad_pcb]
2021-09-07 Move '32 to left on U13.
    [2063-Z80.kicad_pcb]
2021-09-08 Fix inverted DISC_LED signal. Create composite oscillator footprints for X1 and X2. Tidy up the sensitive clock-tracks.
    [2063-Z80-B_Cu.gbl, 2063-Z80-B_Mask.gbs, 2063-Z80-B_Paste.gbp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]
2021-09-08 Freshened up the schematic PDF & 3D rendering.
2021-09-13 Change .1uF parts on BOM.
    [2063-Z80-B_Cu.gbl, 2063-Z80-B_Mask.gbs, 2063-Z80-B_Paste.gbp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]
2021-09-15 Add pull up to SIO (and CTC) IEI.
    [2063-Z80-B_Cu.gbl, 2063-Z80-B_Mask.gbs, 2063-Z80-B_Paste.gbp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]
2021-09-15 Slide J10 away from J3 as much as reasonable
    [2063-Z80-B_Cu.gbl, 2063-Z80-B_Mask.gbs, 2063-Z80-B_Paste.gbp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]
2021-09-16 Ass USER1 jumper on an otherwise unused input.
    [2063-Z80-B_Cu.gbl, 2063-Z80-B_Mask.gbs, 2063-Z80-B_Paste.gbp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]
2021-09-20 Change U11 symbol to a Schmitt NAND
    [2063-Z80.kicad_pcb, 2063-Z80.sch]
2021-09-20 Tweak some part types in the BOM.
    [2063-Z80.sch]
2021-09-20 Freshen up the gerber files.
    [2063-Z80-B_Cu.gbl, 2063-Z80-B_Mask.gbs, 2063-Z80-B_Paste.gbp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]
2021-09-22 Freshen the schematic PDF
2021-10-08 Updated BOM to reflect the asbuilt Rev 3 board.
    [2063-Z80.sch]
2021-10-09 Refresh schematic after BOM updates.
2021-10-13 Revise BOM to reflect the as-built board.
    [2063-Z80.kicad_pcb, 2063-Z80.sch]
2021-10-13 Generate a BOM with clickable datasheet links
    [2063-Z80.sch]
2021-10-13 Clean up BOM values & formatting
    [2063-Z80.kicad_pcb, 2063-Z80.sch]
2021-10-19 Added a BOM of sockets.
2021-10-19 Bold link to FLASH programmer
    Bold the note about ordering the FLASH programmer at the same time as the Z80 board to save money
2021-10-30 Add a link to the Raspberry PI SD card install instructions.
2021-11-12 Add hello_lpt2 to print small banners on an RX-80
2021-12-01 Move ~PRN_LF from U5.17 to U5.25
    [2063-Z80.kicad_pcb, 2063-Z80.sch]
2021-12-01 Change C20 to .47uF to make RESET last 4X longer
    [2063-Z80.sch]
2021-12-01 Add alternate source for SD socket.
    [2063-Z80.sch]
2021-12-01 Make pins U3.1 & U3.30 NC (easier for UV EPROM)
    [2063-Z80.kicad_pcb, 2063-Z80.sch]
2021-12-01 Add pulldown & J12 to A16 for FLASH bank select
    [2063-Z80.kicad_pcb, 2063-Z80.sch]
2021-12-01 Clean up silkscreen.
    [2063-Z80.kicad_pcb]
2021-12-01 Added Rev4 gerbers
    [2063-Z80-B_Cu.gbl, 2063-Z80-B_Mask.gbs, 2063-Z80-B_Paste.gbp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]
2021-12-01 Increase 5V copper to close thru-hole pads
    [2063-Z80-B_Cu.gbl, 2063-Z80-B_Mask.gbs, 2063-Z80-B_Paste.gbp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]
2021-12-01 Add Rev4 PDF schematic.
2021-12-01 Terminate the clock traces.
    [2063-Z80-B_Cu.gbl, 2063-Z80-B_Mask.gbs, 2063-Z80-B_Paste.gbp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]
2021-12-02 Keep more of the main CLK on on front layer
    [2063-Z80-B_Cu.gbl, 2063-Z80-B_Mask.gbs, 2063-Z80-B_Paste.gbp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]
2021-12-14 Make useful the datasheet for the '138
    [2063-Z80.sch]
2021-12-15 Init CTC3 to 19200 & skip a line before printing
2021-12-16 Add links to IDC bits for serial & parallel cables
2021-12-29 Add more baud rates & a timer config
2022-03-15 dd net ties to U3 for EZ-hacking
    [2063-Z80-B_Cu.gbl, 2063-Z80-B_Mask.gbs, 2063-Z80-B_Paste.gbp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]
2022-03-15 Remove the unused map files
    [2063-Z80-NPTH-drl_map.gbr, 2063-Z80-PTH-drl_map.gbr]
2022-03-15 Add script to show diffs btw schematics & gerbers
2022-03-17 Add links to the gerber files.
2022-03-17 Added Where to get Boards & Software
2022-03-22 Change silk screen on U11 from '00 to 74HCT132
    [2063-Z80-B_Cu.gbl, 2063-Z80-B_Mask.gbs, 2063-Z80-B_Paste.gbp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]
2022-03-22 Added TTL serial header & power option.
    [2063-Z80.kicad_pcb, 2063-Z80.sch]
2022-03-22 Remove gerbers (DO NOT BUILD)
    [2063-Z80-B_Cu.gbl, 2063-Z80-B_Mask.gbs, 2063-Z80-B_Paste.gbp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]
2022-03-23 Add USB adapter
    [2063-Z80-B_Cu.gbl, 2063-Z80-B_Mask.gbs, 2063-Z80-B_Paste.gbp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]
2022-03-23 Update PCB image & schematic
    [2063-Z80.kicad_pcb]
2022-03-23 Mark optional USB bits
    [2063-Z80.sch]
2022-07-30 Change teh silkscreen label on U2 to AS6C4008
    [2063-Z80-B_Cu.gbl, 2063-Z80-B_Mask.gbs, 2063-Z80-B_Paste.gbp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]
2022-07-30 Change U2 label on back silkscreen.
    [2063-Z80-B_Cu.gbl, 2063-Z80-B_Mask.gbs, 2063-Z80-B_Paste.gbp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]
2022-07-30 Change the rev number in the silks too
    [2063-Z80-B_Cu.gbl, 2063-Z80-B_Mask.gbs, 2063-Z80-B_Paste.gbp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]
2023-01-18 Add a link to old version of assy lang manual
    Add a link to an early edition of the Assembly Language Programming Manual that does not have the OCR scanning errors in it that are present in the later releases of it in UM0080.
2023-01-28 Change C1, 11 and 12 to .47uF
    [2063-Z80.sch]
2023-02-11 Export PDF after cap value changes Change schematic rev to 4.3.1
    [2063-Z80.sch]
2023-02-11 Fix inconsistent revision number & re-export PDF
    [2063-Z80.sch]
2023-02-19 Get to schematic PDF sans githb fumbling
2023-03-29 Change Digikey numbers on 5-pin headers.
    [2063-Z80.sch]
2023-04-20 Increase pad sizes on SD socket Label R15 and R16 as DNP Move the diffs into their own directory
    [2063-Z80-B_Cu.gbl, 2063-Z80-B_Mask.gbs, 2063-Z80-B_Paste.gbp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]

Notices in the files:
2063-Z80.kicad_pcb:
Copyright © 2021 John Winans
